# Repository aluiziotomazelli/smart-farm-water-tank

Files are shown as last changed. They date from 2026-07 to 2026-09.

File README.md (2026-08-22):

# Smart Farm Water Tank Node






A modular, low-power IoT peripheral node based on the **Seeed Studio XIAO ESP32-C3**, designed to accurately monitor water reservoir levels (via ultrasonic distance sensing and geometric tank modeling), detect high-water overflow/backup state (via float switch with deep-sleep GPIO wakeup), monitor battery health, provide visual diagnostics via a status LED, and transmit telemetry via **ESP-NOW** to the central Smart Farm Hub.

---

## 1. Physical Principle & Measurement Model

- **Ultrasonic Level Sensing:** Measures distance from sensor face to water surface using ultrasonic echo timing. Supports multi-sampling (default 11 samples), noise variance rejection, and automatic retries on weak signal or high variance.
- **Non-Linear Geometric Tank Modeling (`TankGeometry`):** Lookup-table (LUT) and piecewise model for stacked cylindrical tank geometry that converts raw distance (cm) into accurate volume (L) and permille ($\text{‰}$) capacity.
- **Auxiliary Float Switch (`FloatSwitch`):** Redundant physical switch detecting full reservoir conditions. Features multi-sample hysteresis filtering (`FILL_STATE_CONFIRMATIONS_REQUIRED = 2`) to eliminate water ripple turbulence noise, and arms GPIO deep sleep wakeup when tank is empty/falling.
- **Battery Health Monitoring (`BatteryMonitor`):** Measures 1S LiFePO4 / Li-Po battery voltage via calibrated ADC divider, tracking percentage and operating state (`NORMAL`, `LOW`, `CRITICAL`).
- **Power Rail Control (`PowerControl`):** Dedicated power gate rail energizing the ultrasonic sensor only during measurement intervals (~50ms warmup + sample duration) to achieve minimal quiescent sleep current.

---

## 2. Hardware Pinout & Schematic (Seeed XIAO ESP32-C3)

### Pinout Table

| Pin | GPIO | Constant | Description |
| :--- | :--- | :--- | :--- |
| **D0**  | `GPIO 2`  | `FLOAT_SWITCH_GPIO`  | Float switch input with deep-sleep GPIO wakeup trigger |
| **D1**  | `GPIO 3`  | `BATTERY_LEVEL_GPIO` | ADC battery divider input (ADC1_CH3) |
| **D2**  | `GPIO 4`  | `US_TRIG_GPIO` | Ultrasonic sensor Trigger pulse output |
| **D3**  | `GPIO 5`  | `US_ECHO_GPIO` | Ultrasonic sensor Echo input pulse |
| **D4**  | `GPIO 6`  | *(Free)* | General purpose I/O |
| **D5**  | `GPIO 7`  | *(Free)* | General purpose I/O |
| **D6**  | `GPIO 21` | *(Free)* | UART0 TX (Debug serial console) |
| **D7**  | `GPIO 20` | *(Free)* | UART0 RX (Debug serial console) |
| **D8**  | `GPIO 8`  | `STATUS_LED_GPIO` | Status LED visual indicator (diagnostic / state feedback) |
| **D9**  | `GPIO 9`  | `BOOT_BUTTON_GPIO` | Hardware BOOT button / manual OTA mode trigger |
| **D10** | `GPIO 10` | `POWER_GPIO` | Ultrasonic sensor VCC power gating rail |

---

## 3. Architecture & Operational Lifecycle

```
                      +-----------------------------+
                      |         ESP32-C3 Boot       |
                      +-----------------------------+
                                     │
                                     ▼
                      +-----------------------------+
                      |     WaterTankApp::init()    | (LED task, NVS, WiFi, ESP-NOW)
                      +-----------------------------+
                                     │
                                     ▼
                      +-----------------------------+
                      |    Sensor Power Rail ON     | (PowerControl GPIO 10)
                      +-----------------------------+
                                     │
                                     ▼
                      +-----------------------------+
                      |  Read Aux Sensors (Bat/FS)  | (During ~50ms sensor warmup)
                      +-----------------------------+
                                     │
                                     ▼
                      +-----------------------------+
                      | Ultrasonic Sample & Logic   | (Level permille & fill state)
                      +-----------------------------+
                                     │
                                     ▼
                      +-----------------------------+
                      |   Power OFF Sensor Rail     |
                      +-----------------------------+
                                     │
                                     ▼
                      +-----------------------------+
                      | Send Telemetry via ESP-NOW  | (WaterLevelReport + LED TX Pulse)
                      +-----------------------------+
                                     │
                                     ▼
                      +-----------------------------+
                      | Listen Window (200 ms)      | (Process commands: Sync, OTA, Reboot)
                      +-----------------------------+
                                     │
                                     ▼
                      +-----------------------------+
                      | Save State & Stop LED Task  | (AppStorage NVS commit)
                      +-----------------------------+
                                     │
                                     ▼
                      +-----------------------------+
                      |      Enter Deep Sleep       | (Timer + FloatSwitch GPIO Wakeup)
                      +-----------------------------+
```

### Status LED Visual Indicator (`ILedController`)

A background FreeRTOS task animates the status LED non-blockingly without delaying telemetry or sleep routines:

| Pattern | Description |
| :--- | :--- |
| `BOOT_SUCCESS` | 2 short pulses (100ms on / 100ms off) confirming healthy boot initialization |
| `ERROR_BURST` | 5 rapid pulses (50ms on / 50ms off) on hardware or communication faults |
| `PAIRING_MODE` | Continuous 200ms blinking while searching / registering with the Hub |
| `TX_PULSE` | Quick 30ms single blip when broadcasting a telemetry report |
| `OTA_UPDATING` | Continuous 100ms blinking during firmware download and flash write |

---

## 4. Telemetry Format (`WaterLevelReport`)

ESP-NOW telemetry payload packed with fixed binary representation:

```cpp
struct WaterLevelReport
{
    uint16_t level_permille;        ///< Water level in permille (0 - 1000 ‰)
    uint32_t volume_liters;         ///< Calculated water volume in liters
    int16_t  distance_cm;           ///< Raw measured distance from sensor to surface (0.1 cm resolution)
    uint16_t battery_mv;            ///< Node battery voltage in millivolts
    uint8_t  battery_percent;       ///< Node battery percentage (0 - 100%)
    farm::BatteryState battery_state;///< Node battery health state (UNKNOWN, CRITICAL, LOW, NORMAL, FULL)
    farm::FillState fill_state;     ///< Tank fill trend (EMPTY, FILLING, DRAINING, FULL, STABLE)
    farm::SensorStatus status;      ///< Sensor hardware status (OK, ERROR_OUT_OF_RANGE, HW_FAULT)
    bool     float_switch_is_full;  ///< Physical float switch state (true = full)
    bool     backup_mode_active;    ///< True if ultrasonic failed and relying on float switch
    uint64_t unix_time;             ///< UTC Epoch timestamp in milliseconds (0 if unsynced)
};
```

---

## 5. Building and Flashing Firmware

### Prerequisites
- ESP-IDF **v5.1+** (v5.5 recommended)

```bash
# Export ESP-IDF environment
source $HOME/dev/esp/esp-idf/export.sh

# Build target firmware
idf.py set-target esp32c3
idf.py build

# Flash and monitor connected device
idf.py -p /dev/ttyACM0 flash monitor
```

---

## 6. Running Host-Based Tests (Linux)

The codebase is fully decoupled with abstract interfaces and GoogleTest / GoogleMock fixtures, allowing 100% of domain logic, geometry calculations, storage envelopes, and application orchestrator workflows to run natively on Linux.

### Running Individual Test Suites

```bash
# Test geometry lookup and volume calculations
cd host_test/test_water_tank_geometry
idf.py build && ./build/test_water_tank_geometry.elf

# Test edge logic, fill state filtering, and sleep duration calculations
cd host_test/test_water_tank_logic
idf.py build && ./build/test_water_tank_logic.elf

# Test complete application lifecycle, ESP-NOW, OTA, LED, and persistence
cd host_test/test_water_tank_app
idf.py build && ./build/test_water_tank_app.elf
```

### Running All Test Suites with CTest

```bash
cd host_test
mkdir -p build && cd build
cmake ..
ctest --output-on-failure
```

### Generating Unified Code Coverage

```bash
cd host_test/build
cmake --build . --target run_all_tests
# HTML coverage report generated in host_test/coverage/index.html
```

---

## 7. System & Configuration Notes

### Main Task Stack Size
Due to concurrent initialization of `WiFiManager`, `EspNowManager`, UDP Logger, NVS storage backends, and sensors, the peak stack consumption during startup reaches ~3.8 KB.
The main task stack size must be set to at least **8 KB (8192 bytes)**:
```ini
CONFIG_ESP_MAIN_TASK_STACK_SIZE=8192
```
Stack high water mark is monitored at startup and before entering deep sleep via `IHalFreertos::task_get_stack_high_water_mark()` (returns remaining space in bytes).

---

## 8. License

This project is licensed under the MIT License - see the [LICENSE](LICENSE) file for details.

### Third-Party Acknowledgments

- **[ESP-IDF](https://github.com/espressif/esp-idf)**: Copyright (c) Espressif Systems (Shanghai) CO LTD — Licensed under the [Apache License 2.0](https://www.apache.org/licenses/LICENSE-2.0).
- **[Embedded Template Library (ETL)](https://www.etlcpp.com/)**: Copyright (c) John Wellbelove — Licensed under the [MIT License](https://opensource.org/licenses/MIT).
- **[GoogleTest / GoogleMock](https://github.com/google/googletest)**: Copyright (c) Google LLC — Licensed under the [BSD-3-Clause License](https://opensource.org/licenses/BSD-3-Clause).

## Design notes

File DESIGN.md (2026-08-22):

# Smart Farm - Water Tank Node Architecture

## 1. Overview

The **Water Tank Node** is a battery-powered, deep-sleep edge node within the Smart Farm ecosystem. Its primary function is to accurately measure water levels, monitor battery health, execute edge application logic, and transmit telemetry reports to the central Gateway/Hub via ESP-NOW.

---

## 2. System Architecture & Lifecycle

The node implements a deterministic **run-to-completion** operational model designed to minimize active MCU runtime:

```
[Reset / Wakeup] ──► [Init (LED, Storage, WiFi, ESP-NOW, Sensors)]
                           │
                           ▼
                    [Sensor Rail ON] ──► [Aux Read (Battery, FloatSwitch)]
                           │
                           ▼
                    [Ultrasonic Multi-Sample] ──► [Sensor Rail OFF]
                           │
                           ▼
                    [Edge Logic & Fill State Confirmation]
                           │
                           ▼
                    [ESP-NOW WaterLevelReport Transmission (LED TX Pulse)]
                           │
                           ▼
                    [Listen Window (200 ms for Hub Commands)]
                           │
                           ▼
                    [Save State & Stop LED Controller]
                           │
                           ▼
                    [Enter Deep Sleep (Timer + FloatSwitch Wakeup)]
```

### 2.1 Dependency Injection & HAL Decoupling
All hardware-specific APIs (GPIO, ADC, Sleep, Timers, FreeRTOS, NVS, Wi-Fi, System) are abstracted through pure virtual interfaces (`idf_hals` and `smart-farm-common`). The core application orchestrator (`WaterTankApp`) and domain logic (`WaterTankLogic`, `TankGeometry`) have zero direct dependencies on ESP-IDF hardware drivers, enabling comprehensive unit testing on host Linux.

---

## 3. Time Synchronization & Clock Architecture

### 3.1 Design Principles

- **Offline / ESP-NOW Synchronization**: The node does not maintain a continuous Wi-Fi/internet connection for SNTP polling. Time synchronization is received wirelessly from the Hub via ESP-NOW protocol messages.
- **Hardware RTC Persistence**: The ESP32 system clock (`gettimeofday` / POSIX time) is maintained continuously across deep sleep cycles by the hardware RTC memory timer.
- **No Time Regression**: The system does NOT restore cached timestamps from NVS to the system clock on boot. This prevents clock skew and backward time jumps upon waking up.

---

### 3.2 Initialization & Setup

- **Dependency Injection**: The `TimeManager` (`components/time_manager`) is instantiated in `main.cpp` with its HAL dependencies (`HalSntp`, `HalSystemTime`) and injected by reference into `WaterTankApp`.
- **Encapsulated Setup**: During `WaterTankApp::init()`, the private helper `init_time_manager()` configures:
  - Timezone: POSIX string `<-04>4` (UTC-4, no DST).
  - SNTP: `use_dhcp_sntp = false` (local SNTP client disabled).

---

### 3.3 ESP-NOW Time Synchronization Workflow

```
[Hub] ──(ESP-NOW: SYNC_TIME)──> [WaterTankApp::listen_for_messages]
                                             │
                                             ▼
                             [WaterTankApp::process_command]
                                             │
                                             ▼
                        [WaterTankApp::sync_time_from_espnow]
                                             │
                       ┌─────────────────────┴─────────────────────┐
                       ▼                                           ▼
       [time_manager_.sync_from_time_packet]          [CoreStorage Update]
    (Sets System POSIX / ESP32 RTC Clock)        (has_valid_time = true,
                                                  last_sync_unix_time_ms)
```

1. **Message Reception**: During the execution window (`listen_for_messages()`), incoming messages are queued and evaluated by `process_command()`.
2. **Command Processing**: When a payload of `farm::CommandType::SYNC_TIME` (`0x43`) is received, the payload is cast to `farm::TimeSyncCommand`.
3. **Clock Update**: `sync_time_from_espnow()` converts the command to a `time_manager::TimeSyncPacket` (`sync_source = TimeSyncSource::ESP_NOW`) and passes it to `time_manager_.sync_from_time_packet(pkt)`.
4. **Audit State Commit**: On success, `CoreStorage` updates `has_valid_time = true` and `last_sync_unix_time_ms = timestamp_ms` for audit tracking, setting `pending_core_commit_ = true`.

---

### 3.4 Telemetry Sampling & Transmission

1. **Sensor Sample Timestamping**: In `WaterTankApp::run()`, immediately after reading the ultrasonic sensor, the node checks `time_manager_.is_synchronized()`:
   - If synchronized: `stats_.sample_timestamp_ms` = `time_manager_.get_timestamp_ms()`.
   - If unsynchronized: `stats_.sample_timestamp_ms` = `0`.
2. **Telemetry Report Transmission**: In `send_report()`, `farm::WaterLevelReport::unix_time` is populated with `stats_.sample_timestamp_ms` and sent to the Hub over ESP-NOW.

---

### 3.5 Data Structures & Field Definitions

| Data Structure | Field Name | Type | Description |
|---|---|---|---|
| `WaterTankStats` | `sample_timestamp_ms` | `uint64_t` | UTC epoch timestamp (ms) recorded at the exact moment of sensor reading in the current cycle. |
| `CoreStorage` | `has_valid_time` | `bool` | Persistence flag indicating whether the node has received at least one valid time synchronization. |
| `CoreStorage` | `last_sync_unix_time_ms` | `uint64_t` | Audit timestamp (ms) recording the epoch time when the last ESP-NOW sync occurred. |
| `farm::WaterLevelReport` | `unix_time` | `uint64_t` | Sample timestamp (ms) included in the telemetry payload sent to the Hub (`0` if unsynchronized). |

---

## 4. State Management & Storage

### 4.1 Storage Architecture
The node utilizes the `AppStorage<T, Magic, Version>` template pattern (`smart-farm-common`) with `StorageEnvelope`:
- **RTC Memory / RAM Caching**: Runtime state resides in memory and persists across deep sleep wakeups.
- **NVS Flash Throttling**: To maximize Flash endurance, commits to non-volatile storage are throttled to every `NVS_COMMIT_INTERVAL = 10` cycles (~50 minutes in normal operation) unless forced by critical events (e.g. firmware confirmation, time sync, reboot command).
- **Integrity Validation**: CRC32 checksums, magic words (`0x57544E56` for tank stats, `0x434F5245` for core), and schema versioning prevent corrupted reads.

---

## 5. Power & Deep Sleep Management

### 5.1 Power Gating
- The ultrasonic sensor is powered via a high-side P-MOSFET gate on `GPIO 10`. Power is asserted at the start of `run()` and deactivated immediately after valid sampling, reducing sensor standby draw from ~15 mA to 0 µA during sleep.

### 5.2 Dynamic Sleep Interval Calculation
`WaterTankLogic::calculate_sleep_time_us()` determines deep sleep duration according to operational dynamics:
- **Filling / Draining Trend**: Accelerated sampling (~60s) to closely track rapid volume changes.
- **Stable Reservoir**: Extended sampling (300s / 5 min) for battery conservation.
- **Critical Battery / Error State**: Fallback backoff interval to prevent brownout loops.

### 5.3 Float Switch GPIO Wakeup
When the reservoir is empty or falling, `FloatSwitch::should_enable_wakeup()` enables the ESP32-C3 deep sleep GPIO wakeup on `GPIO 2`. A rising water level triggering the float switch immediately wakes the MCU without waiting for timer expiry.

---

## 6. Over-The-Air (OTA) Updates

### 6.1 Trigger Mechanisms
- **Hardware Trigger**: Long press of the BOOT button (`GPIO 9`) captured by `ButtonOtaTrigger`.
- **ESP-NOW Network Trigger**: Remote command (`farm::CommandType::START_OTA`) captured by `EspNowOtaTrigger`.

### 6.2 Execution & Rollback Protection
1. **Radio Handover**: ESP-NOW is stopped and Wi-Fi connects to the local AP using stored credentials.
2. **Download & Flash**: `OtaController` fetches the manifest and streams the firmware binary to the next OTA partition.
3. **Post-Boot Health Check**: Upon rebooting into the new image, `WaterTankApp::check_firmware_healthy()` verifies all peripheral inits. If healthy, the partition is confirmed (`esp_ota_mark_app_valid_cancel_rollback()`). If any init fails, the partition is rejected and the bootloader automatically rolls back to the previous stable firmware slot.

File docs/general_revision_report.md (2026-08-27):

# General Revision Report – Smart Farm Water-Tank Project

## 1. Code Base Overview
- **Modular, layered architecture** – core logic lives in `main/` while hardware-specific abstractions are isolated under `components/` (e.g., `ultrasonic_sensor`, `battery_monitor`, `float_switch`).
- **Dependency-Injection (DI) pattern** is used throughout (`WaterTankApp`, `WaterTankLogic`, `TankGeometry`, etc. receive interfaces via constructors or setters).
- **Interface-driven design** – every hardware domain (GPIO, ADC, NVS, Wi-Fi, ESP-NOW) is wrapped in pure-virtual “hal” interfaces (`i_hal_gpio.hpp`, `i_hal_adc_calibration.hpp`, …) that enable pure-host unit testing.
- **Pure C++ abstractions** – no direct ESP-IDF primitives are exposed above the HAL layer, making the domain code portable to Linux test runners.

## 2. SOLID Alignment
| SOLID Principle | Observed Practices | Comments / Recommendations |
|---|---|---|
| **Single Responsibility** | Each component (`UltrasonicController`, `WaterTankLogic`, `BatteryMonitor`, `FloatSwitchController`) has a clearly defined responsibility (sample, interpret, power-gate, report, etc.). | ✅ Well-aligned. |
| **Open/Closed** | Extensibility is achieved via abstract interfaces (`i_ultrasonic_processor.hpp`, `i_water_tank_nvs.hpp`). New sensor types or storage back-ends can be added without modifying existing code. | ✅ Good. Keep versioning of interfaces to avoid breakage. |
| **Liskov Substitution** | All concrete HAL classes implement the same virtual API and are used only through those abstractions, guaranteeing substitutability. | ✅ Strong adherence. |
| **Interface Segregation** | Very small, purpose-specific interfaces (`i_hal_gpio.hpp`, `i_hal_system_time.hpp`) are provided instead of monolithic "catch-all" bases. | ✅ Clean. |
| **Dependency Inversion** | High-level application (`WaterTankApp`) depends on abstractions (`ILevelSensor`, `IWaterTankStorage`, `ITimeManager`) rather than concrete ESP-IDF drivers. | ✅ Effective; ensure future refinements keep the same abstraction boundaries. |

**Overall SOLID Strength:** Very good – the codebase is organized around abstractions, enabling testability and reuse. Minor refactoring opportunities exist around versioning of storage schemas to keep the system forward-compatible.

## 3. Testing Strategy
- **Host-based test suite** (`host_test/`) runs 100’ % of domain logic on Linux using GoogleTest/GoogleMock.
- **Three logical test suites**: geometry/volume calculations, edge-logic & sleep-time algorithms, full-stack application (ESP-NOW, OTA, LED).
- **Unified coverage generation** – `run_all_tests` target builds all suites and produces an HTML coverage report.
- **CI pipelines** (GitHub Actions) automatically build, test, and publish coverage badges.

**Strengths**
- Comprehensive coverage (>90’ % expected) of non-hardware code.
- Test isolation enables regression testing without flashing hardware.

**Opportunities**
- Add **property-based tests** for mathematical helpers (`TankGeometry`) to catch edge-case conversions.
- Experiment with **mock-based integration tests** for ESP-NOW command flow to increase unit-test depth before hardware integration.
- Document test-suite entry points in the top-level `README` for contributors.

## 4. Documentation Quality
- **README.md** – provides high-level intro, build instructions, hardware pinout, architecture diagram, and flashing steps.
- **DESIGN.md** – deep dive into run-to-completion lifecycle, time-sync design, telemetry schema, power management, and OTA flow.
- **Component-level API docs** (`API.md` in each component) expose public structs, enums, and functions with clear parameter descriptions.
- **Changelog** and **LICENSE** are maintained.

**Strengths**
- Well-structured markdown hierarchy, easy to read.
- Clear diagrams (run-to-completion flowchart, pinout table).
- Telemetry protocol struct is fully documented.

**Opportunities**
- Generate **automatic API docs** (e.g., Doxygen or clang-doc) and publish them as static site for browsing.
- Add "How-to-contribute" section describing branching, PR workflow, and CI expectations.
- Include **run-time stack-size and high-water-mark** expectations in docs (currently only in `DESIGN.md`).

## 5. General Revision Recommendations
| Area | Recommendation | Rationale |
|---|---|---|
| **Code Consistency** | Adopt a **pre-commit formatting check** (clang-format) and enforce via CI. | Keeps style uniform, reduces noise in reviews. |
| **Static Analysis** | Enable **Clang-Tidy** with ESP-IDF rules in the build pipeline. | Early detection of potential undefined-behaviour, resource leaks, and violation of ESP-IDF best-practices. |
| **Versioned Interfaces** | Consider adding a **semantic version tag** (e.g., `IVersioned<T>`) to major abstractions to guard against ABI breakage when evolving storage formats. | Improves forward compatibility across firmware releases. |
| **Telemetry Schema Evolution** | Publish a **schema version field** inside `WaterLevelReport` and document migration paths. | Allows graceful addition of new fields without breaking downstream consumers. |
| **Testing Documentation** | Add a "Running Tests Locally" subsection to `README.md` with concrete commands (`cmake`, `ctest`, coverage). | Lowers onboarding friction for new contributors. |
| **Performance Optimizations** | Profile **deep-sleep wake-up latency** and **stack high-water-mark** on a few representative hardware configurations. Document results. | Guarantees that stack size (`CONFIG_ESP_MAIN_TASK_STACK_SIZE=8192`) remains sufficient after future feature additions. |
| **Security** | Review **ESP-NOW** payload sanitization and consider adding a **message authentication tag** (e.g., HMAC) to prevent spoofing. | Improves robustness of remote command channel. |
| **Accessibility** | Add brief **explanations for non-technical stakeholders** in `DESIGN.md` (e.g., why ultrasonic sensor power-gating matters for battery life). | Enhances knowledge transfer within the broader Smart Farm team. |

## 6. Summary
- The project exhibits a clean, SOLID-compliant architecture with strong DI and interface-driven design.
- Test coverage is thorough for non-hardware domains, supported by automated CI and coverage reporting.
- Documentation is extensive and well organized, though could benefit from automated API generation, additional contribution guidance, and minor schema-versioning documentation.
- The outlined recommendations aim to reinforce code quality, future-proof the telemetry protocol, and streamline contributor onboarding without altering any existing source files.

*Prepared as a high-level revision overview. No code modifications have been performed.*

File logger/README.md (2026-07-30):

# UDP Remote Logger Receiver

Este diretório contém o script utilitário para receber e gravar os logs transmitidos por rede (UDP) a partir dos dispositivos da fazenda inteligente (como o Water Tank e o Hub).

## Como funciona
Os dispositivos, ao estarem conectados na rede Wi-Fi, redirecionam a saída padrão do `ESP_LOGx` para pacotes UDP na porta `4444`. 
Este script escuta essa porta, adiciona um timestamp com milissegundos e o IP do dispositivo de origem, imprimindo na tela e salvando as saídas em arquivo de texto.

## Requisitos
- Apenas Python 3 instalado (usa módulos da biblioteca padrão do Python).

## Como Executar

1. Abra o terminal na pasta deste logger:
   ```bash
   cd logger
   ```

2. Execute o script receiver:
   ```bash
   python3 udp_logger.py
   ```

Os logs serão exibidos no console em tempo real e armazenados em `field_test_logs.txt`.

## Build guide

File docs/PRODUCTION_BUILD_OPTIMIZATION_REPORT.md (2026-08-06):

# Production Build Optimization Report via `sdkconfig` (ESP-IDF / ESP32-C3)

---

## Quick Start: How to Build for Production & Development

### 1. Build for Development / Testing (Default Profile)
Running standard `idf.py build` automatically uses `sdkconfig.defaults.dev` (with `INFO` logs, `-Og` debug optimization, and console output enabled):
```bash
source $HOME/dev/esp/esp-idf/export.sh
idf.py build
```

### 2. Build for Production (Field Release)
To build an optimized production binary (silenced `WARN` logs, `-Os` size optimization, silent assertions, no console output):
```bash
source $HOME/dev/esp/esp-idf/export.sh
idf.py -DSDKCONFIG_DEFAULTS="sdkconfig.defaults;sdkconfig.defaults.esp32c3;sdkconfig.defaults.prod" reconfigure build
```
Tip: You may need to clean your build directory, sdconfig and dependencies.lock 
```bash
rm -rf build sdkconfig dependencies.lock
```

---

## 1. Executive Summary

The **Smart Farm Water Tank** firmware operates on battery power using a *run-to-completion* design pattern paired with *Deep Sleep*.

In a **Production** environment:
- **Shorter CPU active time = Extended battery lifespan.**
- **Smaller binary image = Faster and safer OTA firmware updates.**
- **Log level reduction = Elimination of UART/USB I/O blocking and reduced Flash footprint.**

This document details optimization recommendations and their performance impact when configuring the build system (`sdkconfig.defaults`) for production releases.

---

## 2. Logging and Console (I/O) Optimizations

### A. Application Default Log Level (`CONFIG_LOG_DEFAULT_LEVEL`)
- **Current State**: `CONFIG_LOG_DEFAULT_LEVEL_INFO=y` (`Level 3 - INFO`).
- **Production Recommendation**: `CONFIG_LOG_DEFAULT_LEVEL_WARN=y` (`Level 2 - WARN`) or `CONFIG_LOG_DEFAULT_LEVEL_ERROR=y` (`Level 1 - ERROR`).
- **Impact**:
  1. **Binary Footprint Reduction**: Removes hundreds of `ESP_LOGI` format string constants from Flash memory.
  2. **Execution Speed**: Eliminates CPU cycles spent formatting strings and transmitting via UART/USB during every wake cycle (~5 ms to ~15 ms saved per cycle).

### B. Bootloader Log Level (`CONFIG_BOOTLOADER_LOG_LEVEL`)
- **Current State**: `CONFIG_BOOTLOADER_LOG_LEVEL_INFO=y` (`Level 3`).
- **Production Recommendation**: `CONFIG_BOOTLOADER_LOG_LEVEL_WARN=y` or `CONFIG_BOOTLOADER_LOG_LEVEL_NONE=y`.
- **Impact**: Reduces Bootloader execution time by approximately **10 ms to 20 ms** on every CPU reset (deep sleep wakeup).

### C. Console Output (`CONFIG_ESP_CONSOLE_DEV_NUM` / `CONFIG_ESP_CONSOLE_NONE`)
- **Current State**: `CONFIG_ESP_CONSOLE_USB_SERIAL_JTAG=y`.
- **Production Recommendation**: If field devices do not require physical USB-Serial console debugging, set `CONFIG_ESP_CONSOLE_NONE=y` or disable log colors (`CONFIG_LOG_COLORS=n`).
- **Impact**: Prevents CPU execution stalls when attempting to transmit over USB-Serial JTAG when no host PC is connected.

---

## 3. Compiler and Binary Size Optimizations

### A. GCC Optimization Level (`CONFIG_COMPILER_OPTIMIZATION`)
- **Current State**: `CONFIG_COMPILER_OPTIMIZATION_DEBUG=y` (`-Og`).
- **Production Recommendation**: `CONFIG_COMPILER_OPTIMIZATION_SIZE=y` (`-Os`).
- **Impact**:
  - Enables aggressive GCC code size optimizations.
  - Reduces the `.bin` firmware image size by **20% to 35%**.
  - Improves ESP32-C3 I-Cache efficiency and reduces OTA download transfer time over Wi-Fi.

### B. Assertion Handling (`CONFIG_COMPILER_OPTIMIZATION_ASSERTIONS`)
- **Current State**: `CONFIG_COMPILER_OPTIMIZATION_ASSERTIONS_ENABLE=y`.
- **Production Recommendation**: `CONFIG_COMPILER_OPTIMIZATION_ASSERTIONS_SILENT=y`.
- **Impact**: Preserves system safety (resets the CPU on assertion failure) while **stripping text filenames and line numbers**, saving Flash memory without compromising runtime safety.

---

## 4. PHY Radio and Power Optimizations

### A. Wi-Fi / ESP-NOW Maximum TX Power (`CONFIG_ESP_PHY_MAX_TX_POWER`)
- **Production Recommendation**: Consider lowering maximum PHY radio transmit power from default 20 dBm to ~15–17 dBm (e.g. `CONFIG_ESP_PHY_MAX_TX_POWER=72`).
- **Impact**:
  - Peak radio transmission current drops from **~340 mA to ~190 mA**.
  - Significantly extends battery health and capacity for nodes located within close/medium range of the Hub.

### B. Serial Flash Access Mode (`CONFIG_ESPTOOLPY_FLASHMODE`)
- **Production Recommendation**: If the target hardware board supports 4 data lines (Quad SPI), configure `CONFIG_ESPTOOLPY_FLASHMODE_QIO=y` at 80 MHz instead of Dual I/O (`DIO`).
- **Impact**: Doubles Flash fetch throughput during code execution, reducing total active uptime prior to entering Deep Sleep.

---

## 5. Security and OTA Production Settings

### A. Disable Insecure HTTP Support
- **Current State**: `CONFIG_ESP_HTTPS_OTA_ALLOW_HTTP=y`.
- **Production Recommendation**: Set `CONFIG_ESP_HTTPS_OTA_ALLOW_HTTP=n` (enforce HTTPS once migrating to production cloud/server infrastructure).

---

## 6. Recommended `sdkconfig.defaults.production` Profile

```ini
# =============================================================================
# Production Build Defaults - Smart Farm Water Tank
# =============================================================================

# 1. Compiler Optimization for Size (-Os)
CONFIG_COMPILER_OPTIMIZATION_SIZE=y
# CONFIG_COMPILER_OPTIMIZATION_DEBUG is not set
CONFIG_COMPILER_OPTIMIZATION_ASSERTIONS_SILENT=y

# 2. Logging Optimization (WARN Level & Silence Bootloader)
CONFIG_LOG_DEFAULT_LEVEL_WARN=y
# CONFIG_LOG_DEFAULT_LEVEL_INFO is not set
CONFIG_LOG_DEFAULT_LEVEL=2
CONFIG_BOOTLOADER_LOG_LEVEL_WARN=y
# CONFIG_BOOTLOADER_LOG_LEVEL_INFO is not set
CONFIG_BOOTLOADER_LOG_LEVEL=2
CONFIG_LOG_COLORS=n

# 3. System Task & Rollback Settings
CONFIG_BOOTLOADER_APP_ROLLBACK_ENABLE=y
CONFIG_PARTITION_TABLE_CUSTOM=y
CONFIG_ESP_MAIN_TASK_STACK_SIZE=8192

# 4. Target & Flash
CONFIG_IDF_TARGET="esp32c3"
CONFIG_FREERTOS_UNICORE=y
CONFIG_PM_ENABLE=y
```

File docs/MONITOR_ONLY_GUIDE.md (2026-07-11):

# Guide: Monitor-Only Mode (Without Physical Float Switch)

If you are deploying the system for monitoring only and cannot connect a physical float switch, follow these steps to ensure the battery is protected and the logic remains consistent.

## 1. Prevent Battery Drain in Backup Mode

In the event of an ultrasonic sensor failure, the system enters **Backup Mode**. Without a physical float switch, the system might default to a state of "Tank Not Full," causing it to wake up every 15 seconds to retry the sensor, which will quickly drain the battery.

To prevent this, configure the `FloatSwitch` in `water_tank_app.cpp` so that an open (disconnected) pin is interpreted as **"Tank Full"** (triggering the longer 5-minute sleep).

### Recommended Configuration

Update the `float_switch_config` in `smart-farm-water-tank/main/main.cpp`:

```cpp
floatswitch::Config float_switch_config = {
    .gpio = FLOAT_SWITCH_GPIO,
    .normally_open = true, // Open contact = Tank Full
    .debounce_time_us = 50000,
    .active_level = floatswitch::ActiveLevel::LOW, // internal pull-up will be enabled naturally yielding an open contact
    .wakeup_on = floatswitch::WakeupCondition::NEVER}; // Disable pin wakeup to prevent noise from waking the device
```

## 2. Summary of Configuration Values

| Parameter | Recommended Value | Reason |
| :--- | :--- | :--- |
| `normally_open` | `true` | Ensures that an open/disconnected circuit is interpreted as "Full". |
| `active_level` | `LOW` | Automatically enables the internal pull-up resistor. When the pin is disconnected, it stays HIGH, resulting in an "open" reading. |
| `wakeup_on` | `NEVER` | Prevents the disconnected pin from causing accidental wakeups from electrical noise. |

## 3. Telemetry Impact

With this configuration:
- The `float_switch_is_full` field in the ESP-NOW report will always be `true`.
- If the ultrasonic sensor fails, the system will sleep for `TIMER_STABLE_US` (5 minutes) instead of the 15-second retry timer, preserving your battery until you can fix the sensor.

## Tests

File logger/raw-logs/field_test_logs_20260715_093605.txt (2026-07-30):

[2026-07-15 09:36:07.473] [192.168.1.64] I (124563) UsSensor: 35.4-0, 35.6-0, 35.5-0, 35.5-0, 35.5-0, 35.5-0, 35.6-0
[2026-07-15 09:36:07.510] [192.168.1.64] I (124583) WaterTankApp: Distance: 35.5 - UsResult 0 | Battery: 3810
[2026-07-15 09:36:13.593] [192.168.1.64] I (130683) UsSensor: 35.4-0, 35.6-0, 35.5-0, 36.5-0, 36.5-0, 36.5-0, 36.5-0
[2026-07-15 09:36:13.622] [192.168.1.64] I (130703) WaterTankApp: Distance: 36.1 - UsResult 0 | Battery: 3810
[2026-07-15 09:36:19.713] [192.168.1.64] I (136803) UsSensor: 36.1-0, 36.2-0, 36.2-0, 36.5-0, 36.5-0, 36.5-0, 36.5-0
[2026-07-15 09:36:19.741] [192.168.1.64] I (136823) WaterTankApp: Distance: 36.4 - UsResult 0 | Battery: 3810
[2026-07-15 09:36:25.840] [192.168.1.64] I (142923) UsSensor: 36.1-0, 36.2-0, 36.2-0, 36.2-0, 36.2-0, 36.2-0, 36.5-0
[2026-07-15 09:36:25.891] [192.168.1.64] I (142973) WaterTankApp: Distance: 36.2 - UsResult 0 | Battery: 3810
[2026-07-15 09:36:31.993] [192.168.1.64] I (149073) UsSensor: 36.4-0, 36.5-0, 36.5-0, 36.5-0, 36.2-0, 36.2-0, 36.2-0
[2026-07-15 09:36:32.012] [192.168.1.64] I (149093) WaterTankApp: Distance: 36.4 - UsResult 0 | Battery: 3810
[2026-07-15 09:36:38.102] [192.168.1.64] I (155193) UsSensor: 36.1-0, 36.2-0, 36.2-0, 36.2-0, 36.2-0, 36.2-0, 36.5-0
[2026-07-15 09:36:38.131] [192.168.1.64] I (155213) WaterTankApp: Distance: 36.2 - UsResult 0 | Battery: 3810
[2026-07-15 09:36:44.222] [192.168.1.64] I (161313) UsSensor: 36.1-0, 36.2-0, 36.2-0, 36.2-0, 36.2-0, 36.2-0, 36.2-0
[2026-07-15 09:36:44.250] [192.168.1.64] I (161333) WaterTankApp: Distance: 36.2 - UsResult 0 | Battery: 3810
[2026-07-15 09:36:50.344] [192.168.1.64] I (167433) UsSensor: 37.0-0, 37.1-0, 36.2-0, 36.2-0, 36.2-0, 36.2-0, 37.2-0
[2026-07-15 09:36:50.371] [192.168.1.64] I (167453) WaterTankApp: Distance: 36.6 - UsResult 0 | Battery: 3810
[2026-07-15 09:36:56.462] [192.168.1.64] I (173553) UsSensor: 35.7-0, 35.9-0, 35.9-0, 35.9-0, 35.8-0, 35.9-0, 37.1-0
[2026-07-15 09:36:56.490] [192.168.1.64] I (173573) WaterTankApp: Distance: 36.0 - UsResult 0 | Battery: 3810
[2026-07-15 09:37:02.582] [192.168.1.64] I (179673) UsSensor: 35.8-0, 35.9-0, 35.9-0, 35.9-0, 35.9-0, 35.9-0, 35.9-0
[2026-07-15 09:37:02.610] [192.168.1.64] I (179693) WaterTankApp: Distance: 35.8 - UsResult 0 | Battery: 3810
[2026-07-15 09:37:08.702] [192.168.1.64] I (185793) UsSensor: 35.8-0, 35.8-0, 35.8-0, 35.9-0, 35.9-0, 35.8-0, 35.9-0
[2026-07-15 09:37:08.730] [192.168.1.64] I (185813) WaterTankApp: Distance: 35.8 - UsResult 0 | Battery: 3810
[2026-07-15 09:37:14.821] [192.168.1.64] I (191913) UsSensor: 35.8-0, 35.9-0, 35.9-0, 35.9-0, 35.9-0, 35.9-0, 36.8-0
[2026-07-15 09:37:14.850] [192.168.1.64] I (191933) WaterTankApp: Distance: 36.0 - UsResult 0 | Battery: 3810
[2026-07-15 09:37:20.941] [192.168.1.64] I (198033) UsSensor: 36.7-0, 36.8-0, 36.8-0, 36.8-0, 36.9-0, 36.8-0, 36.9-0
[2026-07-15 09:37:20.971] [192.168.1.64] I (198053) WaterTankApp: Distance: 36.8 - UsResult 0 | Battery: 3810
[2026-07-15 09:37:27.076] [192.168.1.64] I (204153) UsSensor: 36.7-0, 36.9-0, 36.9-0, 36.8-0, 36.8-0, 36.9-0, 35.9-0
[2026-07-15 09:37:27.096] [192.168.1.64] I (204173) WaterTankApp: Distance: 36.7 - UsResult 0 | Battery: 3804
[2026-07-15 09:37:33.181] [192.168.1.64] I (210273) UsSensor: 36.4-0, 36.5-0, 36.5-0, 36.5-0, 36.4-0, 36.5-0, 36.5-0
[2026-07-15 09:37:33.216] [192.168.1.64] I (210293) WaterTankApp: Distance: 36.5 - UsResult 0 | Battery: 3810
[2026-07-15 09:37:39.302] [192.168.1.64] I (216393) UsSensor: 36.4-0, 36.5-0, 36.5-0, 36.4-0, 36.5-0, 36.5-0, 36.5-0
[2026-07-15 09:37:39.329] [192.168.1.64] I (216413) WaterTankApp: Distance: 36.5 - UsResult 0 | Battery: 3810
[2026-07-15 09:37:45.421] [192.168.1.64] I (222513) UsSensor: 36.4-0, 36.5-0, 36.5-0, 36.5-0, 36.5-0, 36.5-0, 36.5-0
[2026-07-15 09:37:45.449] [192.168.1.64] I (222533) WaterTankApp: Distance: 36.5 - UsResult 0 | Battery: 3810
[2026-07-15 09:37:51.546] [192.168.1.64] I (228633) UsSensor: 36.4-0, 36.5-0, 36.5-0, 36.5-0, 36.5-0, 36.5-0, 36.5-0
[2026-07-15 09:37:51.569] [192.168.1.64] I (228653) WaterTankApp: Distance: 36.5 - UsResult 0 | Battery: 3810
[2026-07-15 09:37:57.660] [192.168.1.64] I (234753) UsSensor: 36.4-0, 36.5-0, 36.5-0, 36.5-0, 36.5-0, 36.5-0, 36.5-0
[2026-07-15 09:37:57.690] [192.168.1.64] I (234773) WaterTankApp: Distance: 36.5 - UsResult 0 | Battery: 3810
[2026-07-15 09:38:03.780] [192.168.1.64] I (240873) UsSensor: 36.4-0, 36.4-0, 36.5-0, 36.5-0, 36.4-0, 36.5-0, 36.5-0
[2026-07-15 09:38:03.809] [192.168.1.64] I (240893) WaterTankApp: Distance: 36.5 - UsResult 0 | Battery: 3810
[2026-07-15 09:38:09.900] [192.168.1.64] I (246993) UsSensor: 37.4-0, 37.5-0, 37.5-0, 37.5-0, 37.5-0, 36.5-0, 36.5-0
[2026-07-15 09:38:09.929] [192.168.1.64] I (247013) WaterTankApp: Distance: 37.2 - UsResult 0 | Battery: 3810
[2026-07-15 09:38:16.020] [192.168.1.64] I (253113) UsSensor: 36.4-0, 36.5-0, 36.5-0, 37.5-0, 37.5-0, 37.5-0, 37.5-0
[2026-07-15 09:38:16.056] [192.168.1.64] I (253133) WaterTankApp: Distance: 37.0 - UsResult 0 | Battery: 3810
[2026-07-15 09:38:22.140] [192.168.1.64] I (259233) UsSensor: 37.0-0, 37.5-0, 37.5-0, 37.5-0, 37.5-0, 37.1-0, 37.1-0
[2026-07-15 09:38:22.170] [192.168.1.64] I (259253) WaterTankApp: Distance: 37.3 - UsResult 0 | Battery: 3810
[2026-07-15 09:38:28.260] [192.168.1.64] I (265353) UsSensor: 37.4-0, 37.5-0, 37.2-0, 37.1-0, 37.1-0, 37.1-0, 37.1-0
[2026-07-15 09:38:28.291] [192.168.1.64] I (265373) WaterTankApp: Distance: 37.2 - UsResult 0 | Battery: 3810
[2026-07-15 09:38:34.380] [192.168.1.64] I (271473) UsSensor: 37.0-0, 37.1-0, 36.2-0, 37.1-0, 37.1-0, 37.5-0, 37.5-0
[2026-07-15 09:38:34.408] [192.168.1.64] I (271493) WaterTankApp: Distance: 37.1 - UsResult 0 | Battery: 3810
[2026-07-15 09:38:40.501] [192.168.1.64] I (277593) UsSensor: 36.8-0, 36.8-0, 37.2-0, 37.1-0, 37.1-0, 37.2-0, 37.1-0
[2026-07-15 09:38:40.529] [192.168.1.64] I (277613) WaterTankApp: Distance: 37.0 - UsResult 0 | Battery: 3810
[2026-07-15 09:38:46.620] [192.168.1.64] I (283713) UsSensor: 37.0-0, 37.1-0, 37.1-0, 36.8-0, 36.9-0, 36.8-0, 36.9-0
[2026-07-15 09:38:46.648] [192.168.1.64] I (283733) WaterTankApp: Distance: 37.0 - UsResult 0 | Battery: 3810
[2026-07-15 09:38:52.741] [192.168.1.64] I (289833) UsSensor: 36.7-0, 36.8-0, 36.8-0, 37.5-0, 36.8-0, 36.8-0, 36.8-0
[2026-07-15 09:38:52.768] [192.168.1.64] I (289853) WaterTankApp: Distance: 36.9 - UsResult 0 | Battery: 3810
[2026-07-15 09:38:58.860] [192.168.1.64] I (295953) UsSensor: 36.7-0, 36.8-0, 36.8-0, 36.8-0, 36.9-0, 36.8-0, 36.8-0
[2026-07-15 09:38:58.888] [192.168.1.64] I (295973) WaterTankApp: Distance: 36.8 - UsResult 0 | Battery: 3810
[2026-07-15 09:39:04.979] [192.168.1.64] I (302073) UsSensor: 36.7-0, 36.8-0, 36.8-0, 36.8-0, 36.9-0, 36.8-0, 36.8-0
[2026-07-15 09:39:05.010] [192.168.1.64] I (302093) WaterTankApp: Distance: 36.8 - UsResult 0 | Battery: 3810
[2026-07-15 09:39:11.099] [192.168.1.64] I (308193) UsSensor: 36.7-0, 36.8-0, 36.9-0, 36.8-0, 36.8-0, 36.8-0, 36.8-0
[2026-07-15 09:39:11.128] [192.168.1.64] I (308213) WaterTankApp: Distance: 36.8 - UsResult 0 | Battery: 3810
[2026-07-15 09:39:17.219] [192.168.1.64] I (314313) UsSensor: 33.3-0, 36.5-0, 36.5-0, 36.8-0, 36.8-0, 36.8-0, 36.8-0
[2026-07-15 09:39:17.278] [192.168.1.64] I (314363) WaterTankApp: Distance: 36.2 - UsResult 0 | Battery: 3806
[2026-07-15 09:39:23.370] [192.168.1.64] I (320463) UsSensor: 36.7-0, 36.8-0, 36.5-0, 36.5-0, 36.5-0, 36.5-0, 36.5-0
[2026-07-15 09:39:23.398] [192.168.1.64] I (320483) WaterTankApp: Distance: 36.6 - UsResult 0 | Battery: 3810
[2026-07-15 09:39:29.489] [192.168.1.64] I (326583) UsSensor: 36.7-0, 36.8-0, 36.8-0, 36.5-0, 36.5-0, 36.5-0, 36.8-0
[2026-07-15 09:39:29.517] [192.168.1.64] I (326603) WaterTankApp: Distance: 36.7 - UsResult 0 | Battery: 3810
[2026-07-15 09:39:35.609] [192.168.1.64] I (332703) UsSensor: 36.4-0, 36.5-0, 36.5-0, 36.5-0, 36.5-0, 36.5-0, 36.5-0
[2026-07-15 09:39:35.637] [192.168.1.64] I (332723) WaterTankApp: Distance: 36.5 - UsResult 0 | Battery: 3810
[2026-07-15 09:39:41.729] [192.168.1.64] I (338823) UsSensor: 36.4-0, 36.5-0, 36.5-0, 36.5-0, 36.5-0, 36.5-0, 36.5-0
[2026-07-15 09:39:41.757] [192.168.1.64] I (338843) WaterTankApp: Distance: 36.5 - UsResult 0 | Battery: 3810
[2026-07-15 09:39:47.850] [192.168.1.64] I (344943) UsSensor: 36.4-0, 36.5-0, 36.5-0, 36.5-0, 36.5-0, 36.5-0, 36.5-0
[2026-07-15 09:39:47.878] [192.168.1.64] I (344963) WaterTankApp: Distance: 36.5 - UsResult 0 | Battery: 3810
[2026-07-15 09:39:53.969] [192.168.1.64] I (351063) UsSensor: 37.4-0, 37.5-0, 37.5-0, 36.5-0, 36.5-0, 36.5-0, 36.5-0
[2026-07-15 09:39:53.997] [192.168.1.64] I (351083) WaterTankApp: Distance: 36.9 - UsResult 0 | Battery: 3810
[2026-07-15 09:40:00.093] [192.168.1.64] I (357183) UsSensor: 37.4-0, 37.5-0, 37.5-0, 37.5-0, 37.5-0, 37.5-0, 37.5-0
[2026-07-15 09:40:00.117] [192.168.1.64] I (357203) WaterTankApp: Distance: 37.5 - UsResult 0 | Battery: 3810
[2026-07-15 09:40:06.210] [192.168.1.64] I (363303) UsSensor: 37.4-0, 37.5-0, 37.5-0, 37.5-0, 37.5-0, 37.5-0, 37.5-0
[2026-07-15 09:40:06.240] [192.168.1.64] I (363323) WaterTankApp: Distance: 37.5 - UsResult 0 | Battery: 3810
[2026-07-15 09:40:12.330] [192.168.1.64] I (369423) UsSensor: 37.4-0, 37.5-0, 37.5-0, 37.5-0, 37.5-0, 37.5-0, 37.5-0
[2026-07-15 09:40:12.357] [192.168.1.64] I (369443) WaterTankApp: Distance: 37.5 - UsResult 0 | Battery: 3810
[2026-07-15 09:40:18.450] [192.168.1.64] I (375543) UsSensor: 37.1-0, 37.1-0, 37.1-0, 37.5-0, 37.5-0, 37.5-0, 37.1-0
[2026-07-15 09:40:18.479] [192.168.1.64] I (375563) WaterTankApp: Distance: 37.3 - UsResult 0 | Battery: 3810
[2026-07-15 09:40:24.570] [192.168.1.64] I (381663) UsSensor: 37.1-0, 37.1-0, 37.1-0, 37.1-0, 37.1-0, 37.1-0, 37.2-0
[2026-07-15 09:40:24.596] [192.168.1.64] I (381683) WaterTankApp: Distance: 37.1 - UsResult 0 | Battery: 3810
[2026-07-15 09:40:30.688] [192.168.1.64] I (387783) UsSensor: 37.0-0, 38.1-0, 38.1-0, 38.1-0, 38.1-0, 38.1-0, 37.1-0
[2026-07-15 09:40:30.717] [192.168.1.64] I (387803) WaterTankApp: Distance: 37.8 - UsResult 0 | Battery: 3810
[2026-07-15 09:40:36.808] [192.168.1.64] I (393903) UsSensor: 38.0-0, 38.1-0, 38.1-0, 38.1-0, 37.1-0, 37.1-0, 37.1-0
[2026-07-15 09:40:36.836] [192.168.1.64] I (393923) WaterTankApp: Distance: 37.7 - UsResult 0 | Battery: 3810
[2026-07-15 09:40:42.928] [192.168.1.64] I (400023) UsSensor: 38.0-0, 38.1-0, 38.1-0, 38.1-0, 36.8-0, 36.8-0, 37.8-0
[2026-07-15 09:40:42.962] [192.168.1.64] I (400043) WaterTankApp: Distance: 37.7 - UsResult 0 | Battery: 3810
[2026-07-15 09:40:49.051] [192.168.1.64] I (406143) UsSensor: 36.8-0, 36.8-0, 36.8-0, 36.8-0, 36.8-0, 37.8-0, 37.8-0
[2026-07-15 09:40:49.079] [192.168.1.64] I (406163) WaterTankApp: Distance: 37.1 - UsResult 0 | Battery: 3810
[2026-07-15 09:40:55.169] [192.168.1.64] I (412263) UsSensor: 37.7-0, 37.8-0, 37.8-0, 37.8-0, 36.9-0, 36.8-0, 36.8-0
[2026-07-15 09:40:55.196] [192.168.1.64] I (412283) WaterTankApp: Distance: 37.4 - UsResult 0 | Battery: 3810
[2026-07-15 09:41:01.292] [192.168.1.64] I (418383) UsSensor: 37.7-0, 37.8-0, 37.8-0, 36.8-0, 36.8-0, 36.8-0, 36.8-0
[2026-07-15 09:41:01.316] [192.168.1.64] I (418403) WaterTankApp: Distance: 37.2 - UsResult 0 | Battery: 3810
[2026-07-15 09:41:07.408] [192.168.1.64] I (424503) UsSensor: 36.7-0, 36.9-0, 36.8-0, 37.8-0, 37.8-0, 37.8-0, 37.7-0
[2026-07-15 09:41:07.436] [192.168.1.64] I (424523) WaterTankApp: Distance: 37.4 - UsResult 0 | Battery: 3810
[2026-07-15 09:41:13.528] [192.168.1.64] I (430623) UsSensor: 37.7-0, 37.5-0, 37.5-0, 37.8-0, 37.8-0, 37.8-0, 37.8-0
[2026-07-15 09:41:13.556] [192.168.1.64] I (430643) WaterTankApp: Distance: 37.7 - UsResult 0 | Battery: 3810
[2026-07-15 09:41:19.648] [192.168.1.64] I (436743) UsSensor: 37.7-0, 37.8-0, 37.8-0, 37.8-0, 37.4-0, 37.5-0, 37.5-0
[2026-07-15 09:41:19.676] [192.168.1.64] I (436763) WaterTankApp: Distance: 37.6 - UsResult 0 | Battery: 3810
[2026-07-15 09:41:25.767] [192.168.1.64] I (442863) UsSensor: 37.4-0, 37.5-0, 37.5-0, 37.5-0, 37.5-0, 37.5-0, 37.5-0
[2026-07-15 09:41:25.796] [192.168.1.64] I (442883) WaterTankApp: Distance: 37.5 - UsResult 0 | Battery: 3810
[2026-07-15 09:41:31.889] [192.168.1.64] I (448983) UsSensor: 37.4-0, 37.5-0, 37.5-0, 37.5-0, 37.5-0, 37.5-0, 37.5-0
[2026-07-15 09:41:31.916] [192.168.1.64] I (449003) WaterTankApp: Distance: 37.5 - UsResult 0 | Battery: 3810
[2026-07-15 09:41:38.008] [192.168.1.64] I (455103) UsSensor: 37.4-0, 37.5-0, 37.5-0, 37.5-0, 37.5-0, 37.5-0, 37.5-0
[2026-07-15 09:41:38.037] [192.168.1.64] I (455123) WaterTankApp: Distance: 37.5 - UsResult 0 | Battery: 3810
[2026-07-15 09:41:44.129] [192.168.1.64] I (461223) UsSensor: 37.4-0, 37.5-0, 37.5-0, 37.5-0, 37.5-0, 37.5-0, 37.5-0
[2026-07-15 09:41:44.157] [192.168.1.64] I (461243) WaterTankApp: Distance: 37.5 - UsResult 0 | Battery: 3810
[2026-07-15 09:41:50.247] [192.168.1.64] I (467343) UsSensor: 37.4-0, 37.4-0, 37.5-0, 37.5-0, 37.5-0, 37.5-0, 37.5-0
[2026-07-15 09:41:50.276] [192.168.1.64] I (467363) WaterTankApp: Distance: 37.5 - UsResult 0 | Battery: 3810
[2026-07-15 09:41:56.367] [192.168.1.64] I (473463) UsSensor: 37.4-0, 37.4-0, 37.5-0, 37.5-0, 37.5-0, 37.5-0, 37.5-0
[2026-07-15 09:41:56.395] [192.168.1.64] I (473483) WaterTankApp: Distance: 37.5 - UsResult 0 | Battery: 3810
[2026-07-15 09:42:02.487] [192.168.1.64] I (479583) UsSensor: 37.4-0, 37.5-0, 37.5-0, 37.5-0, 37.5-0, 37.5-0, 37.5-0
[2026-07-15 09:42:02.527] [192.168.1.64] I (479603) WaterTankApp: Distance: 37.5 - UsResult 0 | Battery: 3810
[2026-07-15 09:42:08.607] [192.168.1.64] I (485703) UsSensor: 38.3-0, 38.4-0, 38.4-0, 38.5-0, 38.4-0, 38.4-0, 38.5-0
[2026-07-15 09:42:08.671] [192.168.1.64] I (485753) WaterTankApp: Distance: 38.4 - UsResult 0 | Battery: 3804
[2026-07-15 09:42:14.757] [192.168.1.64] I (491853) UsSensor: 38.3-0, 38.4-0, 38.4-0, 38.4-0, 38.5-0, 38.5-0, 38.5-0
[2026-07-15 09:42:14.785] [192.168.1.64] I (491873) WaterTankApp: Distance: 38.4 - UsResult 0 | Battery: 3810
[2026-07-15 09:42:20.877] [192.168.1.64] I (497973) UsSensor: 38.0-0, 38.1-0, 38.1-0, 38.1-0, 38.1-0, 38.1-0, 38.1-0
[2026-07-15 09:42:20.906] [192.168.1.64] I (497993) WaterTankApp: Distance: 38.1 - UsResult 0 | Battery: 3810
[2026-07-15 09:42:27.000] [192.168.1.64] I (504093) UsSensor: 38.0-0, 38.1-0, 38.1-0, 38.1-0, 38.1-0, 38.1-0, 38.1-0
[2026-07-15 09:42:27.025] [192.168.1.64] I (504113) WaterTankApp: Distance: 38.1 - UsResult 0 | Battery: 3810
[2026-07-15 09:42:33.117] [192.168.1.64] I (510213) UsSensor: 38.0-0, 38.1-0, 38.1-0, 38.1-0, 38.1-0, 38.1-0, 38.1-0
[2026-07-15 09:42:33.148] [192.168.1.64] I (510233) WaterTankApp: Distance: 38.1 - UsResult 0 | Battery: 3810
[2026-07-15 09:42:39.237] [192.168.1.64] I (516333) UsSensor: 38.0-0, 38.1-0, 38.1-0, 38.1-0, 38.1-0, 38.1-0, 38.1-0
[2026-07-15 09:42:39.265] [192.168.1.64] I (516353) WaterTankApp: Distance: 38.1 - UsResult 0 | Battery: 3810
[2026-07-15 09:42:45.357] [192.168.1.64] I (522453) UsSensor: 38.0-0, 38.1-0, 38.1-0, 38.1-0, 38.1-0, 38.1-0, 38.1-0
[2026-07-15 09:42:45.385] [192.168.1.64] I (522473) WaterTankApp: Distance: 38.1 - UsResult 0 | Battery: 3810
[2026-07-15 09:42:51.477] [192.168.1.64] I (528573) UsSensor: 37.7-0, 37.8-0, 37.8-0, 37.8-0, 37.8-0, 37.8-0, 37.8-0
[2026-07-15 09:42:51.505] [192.168.1.64] I (528593) WaterTankApp: Distance: 37.8 - UsResult 0 | Battery: 3810
[2026-07-15 09:42:57.596] [192.168.1.64] I (534693) UsSensor: 37.7-0, 37.8-0, 37.8-0, 37.7-0, 37.8-0, 37.8-0, 37.8-0
[2026-07-15 09:42:57.625] [192.168.1.64] I (534713) WaterTankApp: Distance: 37.8 - UsResult 0 | Battery: 3810
[2026-07-15 09:43:03.717] [192.168.1.64] I (540813) UsSensor: 37.7-0, 37.8-0, 37.7-0, 37.8-0, 37.8-0, 37.7-0, 37.8-0
[2026-07-15 09:43:03.745] [192.168.1.64] I (540833) WaterTankApp: Distance: 37.8 - UsResult 0 | Battery: 3810
[2026-07-15 09:43:09.836] [192.168.1.64] I (546933) UsSensor: 37.7-0, 37.8-0, 37.8-0, 37.8-0, 37.8-0, 37.8-0, 37.8-0
[2026-07-15 09:43:09.865] [192.168.1.64] I (546953) WaterTankApp: Distance: 37.8 - UsResult 0 | Battery: 3810
[2026-07-15 09:43:15.957] [192.168.1.64] I (553053) UsSensor: 37.7-0, 37.8-0, 37.8-0, 37.8-0, 37.8-0, 37.8-0, 37.8-0
[2026-07-15 09:43:15.985] [192.168.1.64] I (553073) WaterTankApp: Distance: 37.8 - UsResult 0 | Battery: 3810
[2026-07-15 09:43:22.076] [192.168.1.64] I (559173) UsSensor: 37.7-0, 37.8-0, 37.8-0, 37.8-0, 37.8-0, 37.8-0, 37.8-0
[2026-07-15 09:43:22.105] [192.168.1.64] I (559193) WaterTankApp: Distance: 37.8 - UsResult 0 | Battery: 3810
[2026-07-15 09:43:28.196] [192.168.1.64] I (565293) UsSensor: 38.7-0, 37.8-0, 37.8-0, 35.9-0, 37.8-0, 37.8-0, 37.8-0
[2026-07-15 09:43:28.224] [192.168.1.64] I (565313) WaterTankApp: Distance: 37.7 - UsResult 0 | Battery: 3810
[2026-07-15 09:43:34.316] [192.168.1.64] I (571413) UsSensor: 37.4-0, 37.5-0, 37.5-0, 37.5-0, 37.5-0, 37.5-0, 37.5-0
[2026-07-15 09:43:34.344] [192.168.1.64] I (571433) WaterTankApp: Distance: 37.5 - UsResult 0 | Battery: 3810
[2026-07-15 09:43:40.436] [192.168.1.64] I (577533) UsSensor: 38.3-0, 38.4-0, 38.4-0, 38.5-0, 38.4-0, 38.4-0, 38.4-0
[2026-07-15 09:43:40.464] [192.168.1.64] I (577553) WaterTankApp: Distance: 38.4 - UsResult 0 | Battery: 3810
[2026-07-15 09:43:46.556] [192.168.1.64] I (583653) UsSensor: 38.3-0, 38.4-0, 38.4-0, 38.4-0, 38.5-0, 38.4-0, 38.5-0
[2026-07-15 09:43:46.584] [192.168.1.64] I (583673) WaterTankApp: Distance: 38.4 - UsResult 0 | Battery: 3810
[2026-07-15 09:43:52.676] [192.168.1.64] I (589773) UsSensor: 38.3-0, 38.5-0, 38.4-0, 38.5-0, 38.5-0, 38.5-0, 38.4-0
[2026-07-15 09:43:52.709] [192.168.1.64] I (589793) WaterTankApp: Distance: 38.4 - UsResult 0 | Battery: 3810
[2026-07-15 09:43:58.796] [192.168.1.64] I (595893) UsSensor: 38.3-0, 38.4-0, 38.4-0, 38.5-0, 38.4-0, 38.4-0, 38.4-0
[2026-07-15 09:43:58.824] [192.168.1.64] I (595913) WaterTankApp: Distance: 38.4 - UsResult 0 | Battery: 3810
[2026-07-15 09:44:04.916] [192.168.1.64] I (602013) UsSensor: 38.3-0, 38.4-0, 38.4-0, 38.4-0, 38.4-0, 38.5-0, 38.4-0
[2026-07-15 09:44:04.944] [192.168.1.64] I (602033) WaterTankApp: Distance: 38.4 - UsResult 0 | Battery: 3810
[2026-07-15 09:44:11.038] [192.168.1.64] I (608133) UsSensor: 38.3-0, 38.4-0, 38.4-0, 38.4-0, 38.4-0, 38.5-0, 38.4-0
[2026-07-15 09:44:11.071] [192.168.1.64] I (608153) WaterTankApp: Distance: 38.4 - UsResult 0 | Battery: 3810
[2026-07-15 09:44:17.156] [192.168.1.64] I (614253) UsSensor: 38.3-0, 38.4-0, 38.4-0, 38.4-0, 38.4-0, 38.5-0, 38.4-0
[2026-07-15 09:44:17.184] [192.168.1.64] I (614273) WaterTankApp: Distance: 38.4 - UsResult 0 | Battery: 3810
[2026-07-15 09:44:23.276] [192.168.1.64] I (620373) UsSensor: 38.3-0, 38.4-0, 38.4-0, 38.4-0, 38.4-0, 38.4-0, 38.4-0
[2026-07-15 09:44:23.304] [192.168.1.64] I (620393) WaterTankApp: Distance: 38.4 - UsResult 0 | Battery: 3810
[2026-07-15 09:44:29.398] [192.168.1.64] I (626493) UsSensor: 38.3-0, 38.5-0, 38.4-0, 38.4-0, 38.4-0, 38.4-0, 38.4-0
[2026-07-15 09:44:29.424] [192.168.1.64] I (626513) WaterTankApp: Distance: 38.4 - UsResult 0 | Battery: 3810
[2026-07-15 09:44:35.516] [192.168.1.64] I (632613) UsSensor: 38.3-0, 38.4-0, 38.4-0, 38.4-0, 38.5-0, 38.4-0, 38.4-0
[2026-07-15 09:44:35.544] [192.168.1.64] I (632633) WaterTankApp: Distance: 38.4 - UsResult 0 | Battery: 3810
[2026-07-15 09:44:41.636] [192.168.1.64] I (638733) UsSensor: 38.3-0, 38.4-0, 38.5-0, 38.4-0, 38.4-0, 38.4-0, 38.4-0
[2026-07-15 09:44:41.665] [192.168.1.64] I (638753) WaterTankApp: Distance: 38.4 - UsResult 0 | Battery: 3810
[2026-07-15 09:44:47.756] [192.168.1.64] I (644853) UsSensor: 38.3-0, 38.4-0, 38.4-0, 38.4-0, 38.4-0, 38.4-0, 38.4-0
[2026-07-15 09:44:47.784] [192.168.1.64] I (644873) WaterTankApp: Distance: 38.4 - UsResult 0 | Battery: 3810
[2026-07-15 09:44:53.876] [192.168.1.64] I (650973) UsSensor: 38.4-0, 38.5-0, 38.4-0, 38.4-0, 38.4-0, 38.4-0, 38.4-0
[2026-07-15 09:44:53.904] [192.168.1.64] I (650993) WaterTankApp: Distance: 38.4 - UsResult 0 | Battery: 3810
[2026-07-15 09:44:59.998] [192.168.1.64] I (657093) UsSensor: 38.3-0, 38.4-0, 38.5-0, 38.4-0, 38.4-0, 38.4-0, 38.5-0
[2026-07-15 09:45:00.060] [192.168.1.64] I (657143) WaterTankApp: Distance: 38.4 - UsResult 0 | Battery: 3804
[2026-07-15 09:45:06.153] [192.168.1.64] I (663243) UsSensor: 38.3-0, 38.4-0, 38.4-0, 38.4-0, 38.4-0, 38.4-0, 38.4-0
[2026-07-15 09:45:06.174] [192.168.1.64] I (663263) WaterTankApp: Distance: 38.4 - UsResult 0 | Battery: 3810
[2026-07-15 09:45:12.274] [192.168.1.64] I (669363) UsSensor: 38.3-0, 38.4-0, 38.5-0, 38.4-0, 38.4-0, 38.4-0, 38.5-0
[2026-07-15 09:45:12.294] [192.168.1.64] I (669383) WaterTankApp: Distance: 38.4 - UsResult 0 | Battery: 3810
[2026-07-15 09:45:18.385] [192.168.1.64] I (675483) UsSensor: 38.3-0, 38.4-0, 38.4-0, 38.4-0, 38.4-0, 38.4-0, 38.4-0
[2026-07-15 09:45:18.417] [192.168.1.64] I (675503) WaterTankApp: Distance: 38.4 - UsResult 0 | Battery: 3810
[2026-07-15 09:45:24.505] [192.168.1.64] I (681603) UsSensor: 38.4-0, 38.4-0, 38.4-0, 38.5-0, 38.4-0, 38.4-0, 38.4-0
[2026-07-15 09:45:24.533] [192.168.1.64] I (681623) WaterTankApp: Distance: 38.4 - UsResult 0 | Battery: 3810
[2026-07-15 09:45:30.625] [192.168.1.64] I (687723) UsSensor: 38.3-0, 38.4-0, 38.4-0, 38.4-0, 38.4-0, 38.4-0, 38.4-0
[2026-07-15 09:45:30.653] [192.168.1.64] I (687743) WaterTankApp: Distance: 38.4 - UsResult 0 | Battery: 3810
[2026-07-15 09:45:36.747] [192.168.1.64] I (693843) UsSensor: 38.3-0, 38.4-0, 38.4-0, 38.4-0, 38.4-0, 38.4-0, 38.4-0
[2026-07-15 09:45:36.773] [192.168.1.64] I (693863) WaterTankApp: Distance: 38.4 - UsResult 0 | Battery: 3810
[2026-07-15 09:45:42.865] [192.168.1.64] I (699963) UsSensor: 38.3-0, 38.4-0, 38.4-0, 38.4-0, 38.4-0, 38.4-0, 38.4-0
[2026-07-15 09:45:42.894] [192.168.1.64] I (699983) WaterTankApp: Distance: 38.4 - UsResult 0 | Battery: 3810
[2026-07-15 09:45:48.989] [192.168.1.64] I (706083) UsSensor: 38.3-0, 38.4-0, 38.4-0, 38.4-0, 38.4-0, 38.5-0, 38.4-0
[2026-07-15 09:45:49.016] [192.168.1.64] I (706103) WaterTankApp: Distance: 38.4 - UsResult 0 | Battery: 3810
[2026-07-15 09:45:55.105] [192.168.1.64] I (712203) UsSensor: 38.3-0, 38.4-0, 38.4-0, 38.5-0, 38.4-0, 38.4-0, 38.4-0
[2026-07-15 09:45:55.133] [192.168.1.64] I (712223) WaterTankApp: Distance: 38.4 - UsResult 0 | Battery: 3810
[2026-07-15 09:46:01.225] [192.168.1.64] I (718323) UsSensor: 38.3-0, 38.4-0, 38.4-0, 38.4-0, 38.4-0, 38.4-0, 38.4-0
[2026-07-15 09:46:01.253] [192.168.1.64] I (718343) WaterTankApp: Distance: 38.4 - UsResult 0 | Battery: 3810
[2026-07-15 09:46:07.345] [192.168.1.64] I (724443) UsSensor: 38.3-0, 38.4-0, 38.4-0, 38.4-0, 38.4-0, 38.5-0, 38.4-0
[2026-07-15 09:46:07.373] [192.168.1.64] I (724463) WaterTankApp: Distance: 38.4 - UsResult 0 | Battery: 3810
[2026-07-15 09:46:13.465] [192.168.1.64] I (730563) UsSensor: 38.3-0, 38.5-0, 38.4-0, 38.4-0, 38.5-0, 38.4-0, 38.4-0
[2026-07-15 09:46:13.493] [192.168.1.64] I (730583) WaterTankApp: Distance: 38.4 - UsResult 0 | Battery: 3810
[2026-07-15 09:46:19.585] [192.168.1.64] I (736683) UsSensor: 38.3-0, 38.4-0, 38.4-0, 38.5-0, 38.4-0, 38.4-0, 38.4-0
[2026-07-15 09:46:19.613] [192.168.1.64] I (736703) WaterTankApp: Distance: 38.4 - UsResult 0 | Battery: 3810
[2026-07-15 09:46:25.711] [192.168.1.64] I (742803) UsSensor: 38.3-0, 38.4-0, 38.4-0, 38.4-0, 38.4-0, 38.4-0, 38.4-0
[2026-07-15 09:46:25.733] [192.168.1.64] I (742823) WaterTankApp: Distance: 38.4 - UsResult 0 | Battery: 3810
[2026-07-15 09:46:31.825] [192.168.1.64] I (748923) UsSensor: 38.3-0, 38.4-0, 38.4-0, 38.4-0, 38.4-0, 38.4-0, 38.4-0
[2026-07-15 09:46:31.853] [192.168.1.64] I (748943) WaterTankApp: Distance: 38.4 - UsResult 0 | Battery: 3810
[2026-07-15 09:46:37.950] [192.168.1.64] I (755043) UsSensor: 38.3-0, 38.4-0, 38.4-0, 38.4-0, 38.4-0, 38.4-0, 38.4-0
[2026-07-15 09:46:37.982] [192.168.1.64] I (755063) WaterTankApp: Distance: 38.4 - UsResult 0 | Battery: 3810
[2026-07-15 09:46:44.071] [192.168.1.64] I (761163) UsSensor: 38.3-0, 38.4-0, 38.4-0, 38.4-0, 38.4-0, 38.4-0, 38.4-0
[2026-07-15 09:46:44.097] [192.168.1.64] I (761183) WaterTankApp: Distance: 38.4 - UsResult 0 | Battery: 3810
[2026-07-15 09:46:50.185] [192.168.1.64] I (767283) UsSensor: 38.3-0, 38.1-0, 38.5-0, 38.4-0, 38.4-0, 38.4-0, 38.4-0
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

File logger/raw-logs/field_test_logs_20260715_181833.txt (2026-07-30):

[2026-07-15 18:22:30.433] [192.168.1.64] I (6230) esp_netif_handlers: sta ip: 192.168.1.64, mask: 255.255.255.0, gw: 192.168.1.1
[2026-07-15 18:22:31.058] [192.168.1.64] <ba-add>idx:0 (ifx:0, 3e:4e:05:24:7d:3b), tid:5, ssn:6, winSize:64
[2026-07-15 18:22:31.058] [192.168.1.64] 
[2026-07-15 18:22:32.087] [192.168.1.64] I (8200) UsSensor: 39.7-0, 40.4-0, 40.1-0, 40.1-0, 40.1-0, 40.1-0, 40.4-0
[2026-07-15 18:22:32.112] [192.168.1.64] I (8220) WaterTankApp: Distance: 40.1 - UsResult 0 | Battery: 3778
[2026-07-15 18:22:38.204] [192.168.1.64] I (14320) UsSensor: 39.9-0, 40.1-0, 40.1-0, 40.1-0, 40.4-0, 40.4-0, 39.4-0
[2026-07-15 18:22:38.233] [192.168.1.64] I (14340) WaterTankApp: Distance: 40.1 - UsResult 0 | Battery: 3780
[2026-07-15 18:22:44.324] [192.168.1.64] I (20440) UsSensor: 40.3-0, 40.4-0, 40.4-0, 40.4-0, 40.4-0, 40.4-0, 40.4-0
[2026-07-15 18:22:44.358] [192.168.1.64] I (20460) WaterTankApp: Distance: 40.4 - UsResult 0 | Battery: 3780
[2026-07-15 18:22:50.444] [192.168.1.64] I (26560) UsSensor: 40.3-0, 40.4-0, 40.4-0, 40.4-0, 39.4-0, 39.4-0, 39.4-0
[2026-07-15 18:22:50.472] [192.168.1.64] I (26580) WaterTankApp: Distance: 40.0 - UsResult 0 | Battery: 3780
[2026-07-15 18:22:56.564] [192.168.1.64] I (32680) UsSensor: 40.0-0, 40.1-0, 40.4-0, 40.7-0, 40.4-0, 40.4-0, 40.1-0
[2026-07-15 18:22:56.592] [192.168.1.64] I (32700) WaterTankApp: Distance: 40.3 - UsResult 0 | Battery: 3780
[2026-07-15 18:23:02.688] [192.168.1.64] I (38800) UsSensor: 40.0-0, 40.1-0, 40.0-0, 40.0-0, 40.4-0, 40.4-0, 39.4-0
[2026-07-15 18:23:02.712] [192.168.1.64] I (38820) WaterTankApp: Distance: 40.1 - UsResult 0 | Battery: 3778
[2026-07-15 18:23:08.804] [192.168.1.64] I (44920) UsSensor: 40.3-0, 40.4-0, 40.4-0, 40.4-0, 40.0-0, 40.0-0, 40.1-0
[2026-07-15 18:23:08.863] [192.168.1.64] I (44970) WaterTankApp: Distance: 40.2 - UsResult 0 | Battery: 3772
[2026-07-15 18:23:14.954] [192.168.1.64] I (51070) UsSensor: 40.9-0, 41.0-0, 41.0-0, 40.1-0, 40.0-0, 40.1-0, 40.0-0
[2026-07-15 18:23:14.984] [192.168.1.64] I (51090) WaterTankApp: Distance: 40.4 - UsResult 0 | Battery: 3774
[2026-07-15 18:23:21.074] [192.168.1.64] I (57190) UsSensor: 40.0-0, 40.0-0, 40.1-0, 40.1-0, 40.0-0, 40.1-0, 40.4-0
[2026-07-15 18:23:21.102] [192.168.1.64] I (57210) WaterTankApp: Distance: 40.1 - UsResult 0 | Battery: 3774
[2026-07-15 18:23:27.194] [192.168.1.64] I (63310) UsSensor: 39.3-0, 40.7-0, 39.4-0, 40.4-0, 40.4-0, 40.1-0, 40.1-0
[2026-07-15 18:23:27.222] [192.168.1.64] I (63330) WaterTankApp: Distance: 40.1 - UsResult 0 | Battery: 3772
[2026-07-15 18:23:33.314] [192.168.1.64] I (69430) UsSensor: 40.3-0, 40.1-0, 40.1-0, 40.0-0, 40.4-0, 40.4-0, 40.4-0
[2026-07-15 18:23:33.342] [192.168.1.64] I (69450) WaterTankApp: Distance: 40.2 - UsResult 0 | Battery: 3778
[2026-07-15 18:23:39.434] [192.168.1.64] I (75550) UsSensor: 40.3-0, 40.4-0, 40.4-0, 40.4-0, 40.4-0, 40.4-0, 40.4-0
[2026-07-15 18:23:39.462] [192.168.1.64] I (75570) WaterTankApp: Distance: 40.4 - UsResult 0 | Battery: 3774
[2026-07-15 18:23:45.554] [192.168.1.64] I (81670) UsSensor: 40.0-0, 40.3-0, 40.4-0, 40.4-0, 40.4-0, 40.1-0, 40.1-0
[2026-07-15 18:23:45.582] [192.168.1.64] I (81690) WaterTankApp: Distance: 40.2 - UsResult 0 | Battery: 3776
[2026-07-15 18:23:51.674] [192.168.1.64] I (87790) UsSensor: 40.0-0, 40.7-0, 40.7-0, 41.0-0, 40.1-0, 40.0-0, 40.4-0
[2026-07-15 18:23:51.702] [192.168.1.64] I (87810) WaterTankApp: Distance: 40.4 - UsResult 0 | Battery: 3772
[2026-07-15 18:23:57.794] [192.168.1.64] I (93910) UsSensor: 40.0-0, 40.1-0, 40.4-0, 40.4-0, 40.1-0, 40.1-0, 40.0-0
[2026-07-15 18:23:57.822] [192.168.1.64] I (93930) WaterTankApp: Distance: 40.2 - UsResult 0 | Battery: 3776
[2026-07-15 18:24:03.914] [192.168.1.64] I (100030) UsSensor: 40.0-0, 40.4-0, 40.1-0, 40.0-0, 40.0-0, 40.1-0, 40.1-0
[2026-07-15 18:24:03.942] [192.168.1.64] I (100050) WaterTankApp: Distance: 40.1 - UsResult 0 | Battery: 3774
[2026-07-15 18:24:10.034] [192.168.1.64] I (106150) UsSensor: 40.3-0, 40.1-0, 40.1-0, 40.1-0, 40.1-0, 40.0-0, 40.4-0
[2026-07-15 18:24:10.068] [192.168.1.64] I (106170) WaterTankApp: Distance: 40.1 - UsResult 0 | Battery: 3776
[2026-07-15 18:24:16.154] [192.168.1.64] I (112270) UsSensor: 40.0-0, 40.4-0, 40.4-0, 40.4-0, 40.4-0, 40.4-0, 40.1-0
[2026-07-15 18:24:16.182] [192.168.1.64] I (112290) WaterTankApp: Distance: 40.3 - UsResult 0 | Battery: 3778
[2026-07-15 18:24:22.274] [192.168.1.64] I (118390) UsSensor: 40.0-0, 40.0-0, 40.1-0, 40.1-0, 40.0-0, 40.1-0, 40.1-0
[2026-07-15 18:24:22.302] [192.168.1.64] I (118410) WaterTankApp: Distance: 40.0 - UsResult 0 | Battery: 3776
[2026-07-15 18:24:28.398] [192.168.1.64] I (124510) UsSensor: 40.0-0, 41.0-0, 41.0-0, 40.1-0, 40.0-0, 40.1-0, 40.1-0
[2026-07-15 18:24:28.422] [192.168.1.64] I (124530) WaterTankApp: Distance: 40.3 - UsResult 0 | Battery: 3778
[2026-07-15 18:24:34.514] [192.168.1.64] I (130630) UsSensor: 40.9-0, 41.0-0, 40.1-0, 40.1-0, 40.1-0, 40.0-0, 40.0-0
[2026-07-15 18:24:34.542] [192.168.1.64] I (130650) WaterTankApp: Distance: 40.3 - UsResult 0 | Battery: 3774
[2026-07-15 18:24:40.634] [192.168.1.64] I (136750) UsSensor: 40.0-0, 40.1-0, 41.0-0, 40.7-0, 40.7-0, 40.7-0, 41.0-0
[2026-07-15 18:24:40.662] [192.168.1.64] I (136770) WaterTankApp: Distance: 40.6 - UsResult 0 | Battery: 3774
[2026-07-15 18:24:46.754] [192.168.1.64] I (142870) UsSensor: 40.0-0, 40.1-0, 40.1-0, 40.1-0, 40.1-0, 40.1-0, 40.0-0
[2026-07-15 18:24:46.782] [192.168.1.64] I (142890) WaterTankApp: Distance: 40.1 - UsResult 0 | Battery: 3772
[2026-07-15 18:24:52.874] [192.168.1.64] I (148990) UsSensor: 40.0-0, 40.0-0, 40.0-0, 40.1-0, 40.0-0, 40.1-0, 40.0-0
[2026-07-15 18:24:52.902] [192.168.1.64] I (149010) WaterTankApp: Distance: 40.0 - UsResult 0 | Battery: 3776
[2026-07-15 18:24:58.994] [192.168.1.64] I (155110) UsSensor: 40.0-0, 40.1-0, 40.1-0, 41.0-0, 41.0-0, 41.0-0, 40.1-0
[2026-07-15 18:24:59.024] [192.168.1.64] I (155130) WaterTankApp: Distance: 40.5 - UsResult 0 | Battery: 3780
[2026-07-15 18:25:05.114] [192.168.1.64] I (161230) UsSensor: 40.6-0, 40.7-0, 40.1-0, 40.1-0, 40.1-0, 40.1-0, 40.1-0
[2026-07-15 18:25:05.142] [192.168.1.64] I (161250) WaterTankApp: Distance: 40.2 - UsResult 0 | Battery: 3778
[2026-07-15 18:25:11.234] [192.168.1.64] I (167350) UsSensor: 40.0-0, 40.1-0, 40.1-0, 41.0-0, 41.0-0, 40.1-0, 40.0-0
[2026-07-15 18:25:11.263] [192.168.1.64] I (167370) WaterTankApp: Distance: 40.3 - UsResult 0 | Battery: 3776
[2026-07-15 18:25:17.355] [192.168.1.64] I (173470) UsSensor: 40.0-0, 40.1-0, 40.0-0, 40.1-0, 41.0-0, 41.0-0, 41.0-0
[2026-07-15 18:25:17.382] [192.168.1.64] I (173490) WaterTankApp: Distance: 40.5 - UsResult 0 | Battery: 3778
[2026-07-15 18:25:23.475] [192.168.1.64] I (179590) UsSensor: 40.9-0, 40.1-0, 40.0-0, 40.1-0, 40.0-0, 40.1-0, 40.0-0
[2026-07-15 18:25:23.502] [192.168.1.64] I (179610) WaterTankApp: Distance: 40.2 - UsResult 0 | Battery: 3780
[2026-07-15 18:25:29.594] [192.168.1.64] I (185710) UsSensor: 40.0-0, 40.1-0, 40.1-0, 40.1-0, 40.1-0, 41.0-0, 40.1-0
[2026-07-15 18:25:29.622] [192.168.1.64] I (185730) WaterTankApp: Distance: 40.2 - UsResult 0 | Battery: 3776
[2026-07-15 18:25:35.714] [192.168.1.64] I (191830) UsSensor: 40.0-0, 40.1-0, 40.1-0, 40.0-0, 40.1-0, 40.1-0, 40.1-0
[2026-07-15 18:25:35.742] [192.168.1.64] I (191850) WaterTankApp: Distance: 40.1 - UsResult 0 | Battery: 3774
[2026-07-15 18:25:41.834] [192.168.1.64] I (197950) UsSensor: 40.9-0, 41.0-0, 41.0-0, 40.1-0, 40.1-0, 40.1-0, 40.1-0
[2026-07-15 18:25:41.862] [192.168.1.64] I (197970) WaterTankApp: Distance: 40.5 - UsResult 0 | Battery: 3776
[2026-07-15 18:25:47.954] [192.168.1.64] I (204070) UsSensor: 40.0-0, 40.1-0, 40.0-0, 40.1-0, 44.1-0, 41.0-0, 40.7-0
[2026-07-15 18:25:47.982] [192.168.1.64] I (204090) WaterTankApp: Distance: 40.9 - UsResult 0 | Battery: 3772
[2026-07-15 18:25:54.075] [192.168.1.64] I (210190) UsSensor: 40.9-0, 40.7-0, 40.7-0, 41.0-0, 41.0-0, 41.0-0, 40.1-0
[2026-07-15 18:25:54.108] [192.168.1.64] I (210210) WaterTankApp: Distance: 40.8 - UsResult 0 | Battery: 3780
[2026-07-15 18:26:00.194] [192.168.1.64] I (216310) UsSensor: 40.0-0, 40.1-0, 40.0-0, 40.1-0, 41.0-0, 41.0-0, 41.0-0
[2026-07-15 18:26:00.252] [192.168.1.64] I (216360) WaterTankApp: Distance: 40.5 - UsResult 0 | Battery: 3772
[2026-07-15 18:26:06.344] [192.168.1.64] I (222460) UsSensor: 40.0-0, 40.1-0, 40.1-0, 40.1-0, 40.1-0, 40.0-0, 41.0-0
[2026-07-15 18:26:06.372] [192.168.1.64] I (222480) WaterTankApp: Distance: 40.2 - UsResult 0 | Battery: 3778
[2026-07-15 18:26:12.464] [192.168.1.64] I (228580) UsSensor: 40.9-0, 41.0-0, 41.0-0, 40.1-0, 40.0-0, 40.1-0, 40.1-0
[2026-07-15 18:26:12.492] [192.168.1.64] I (228600) WaterTankApp: Distance: 40.4 - UsResult 0 | Battery: 3776
[2026-07-15 18:26:18.584] [192.168.1.64] I (234700) UsSensor: 40.0-0, 40.1-0, 40.1-0, 40.1-0, 40.0-0, 41.0-0, 41.0-0
[2026-07-15 18:26:18.612] [192.168.1.64] I (234720) WaterTankApp: Distance: 40.3 - UsResult 0 | Battery: 3774
[2026-07-15 18:26:24.704] [192.168.1.64] I (240820) UsSensor: 40.9-0, 41.0-0, 40.9-0, 41.0-0, 41.0-0, 40.1-0, 40.1-0
[2026-07-15 18:26:24.737] [192.168.1.64] I (240840) WaterTankApp: Distance: 40.7 - UsResult 0 | Battery: 3778
[2026-07-15 18:26:30.824] [192.168.1.64] I (246940) UsSensor: 40.9-0, 41.0-0, 41.0-0, 41.0-0, 41.0-0, 41.0-0, 40.1-0
[2026-07-15 18:26:30.852] [192.168.1.64] I (246960) WaterTankApp: Distance: 40.9 - UsResult 0 | Battery: 3780
[2026-07-15 18:26:36.944] [192.168.1.64] I (253060) UsSensor: 40.0-0, 40.1-0, 40.1-0, 40.0-0, 41.0-0, 41.0-0, 41.0-0
[2026-07-15 18:26:36.972] [192.168.1.64] I (253080) WaterTankApp: Distance: 40.5 - UsResult 0 | Battery: 3772
[2026-07-15 18:26:43.065] [192.168.1.64] I (259180) UsSensor: 40.0-0, 41.0-0, 41.0-0, 41.0-0, 41.0-0, 40.1-0, 40.1-0
[2026-07-15 18:26:43.094] [192.168.1.64] I (259200) WaterTankApp: Distance: 40.6 - UsResult 0 | Battery: 3776
[2026-07-15 18:26:49.184] [192.168.1.64] I (265300) UsSensor: 40.0-0, 40.1-0, 40.1-0, 40.1-0, 40.1-0, 40.0-0, 40.0-0
[2026-07-15 18:26:49.212] [192.168.1.64] I (265320) WaterTankApp: Distance: 40.1 - UsResult 0 | Battery: 3780
[2026-07-15 18:26:55.304] [192.168.1.64] I (271420) UsSensor: 40.0-0, 40.1-0, 40.0-0, 40.1-0, 40.0-0, 40.1-0, 40.1-0
[2026-07-15 18:26:55.332] [192.168.1.64] I (271440) WaterTankApp: Distance: 40.1 - UsResult 0 | Battery: 3776
[2026-07-15 18:27:01.425] [192.168.1.64] I (277540) UsSensor: 40.9-0, 41.0-0, 41.0-0, 41.0-0, 41.0-0, 41.0-0, 40.1-0
[2026-07-15 18:27:01.452] [192.168.1.64] I (277560) WaterTankApp: Distance: 40.9 - UsResult 0 | Battery: 3776
[2026-07-15 18:27:07.544] [192.168.1.64] I (283660) UsSensor: 40.9-0, 41.0-0, 41.0-0, 40.0-0, 40.1-0, 40.1-0, 40.1-0
[2026-07-15 18:27:07.572] [192.168.1.64] I (283680) WaterTankApp: Distance: 40.5 - UsResult 0 | Battery: 3774
[2026-07-15 18:27:13.664] [192.168.1.64] I (289780) UsSensor: 40.0-0, 40.1-0, 41.0-0, 41.0-0, 41.0-0, 41.0-0, 41.0-0
[2026-07-15 18:27:13.692] [192.168.1.64] I (289800) WaterTankApp: Distance: 40.7 - UsResult 0 | Battery: 3774
[2026-07-15 18:27:19.784] [192.168.1.64] I (295900) UsSensor: 40.0-0, 40.1-0, 40.0-0, 37.0-0, 40.1-0, 41.0-0, 41.0-0
[2026-07-15 18:27:19.817] [192.168.1.64] I (295920) WaterTankApp: Distance: 39.9 - UsResult 0 | Battery: 3774
[2026-07-15 18:27:25.904] [192.168.1.64] I (302020) UsSensor: 40.0-0, 40.1-0, 40.0-0, 40.1-0, 40.0-0, 40.1-0, 40.0-0
[2026-07-15 18:27:25.932] [192.168.1.64] I (302040) WaterTankApp: Distance: 40.0 - UsResult 0 | Battery: 3772
[2026-07-15 18:27:32.024] [192.168.1.64] I (308140) UsSensor: 40.0-0, 40.1-0, 40.1-0, 40.0-0, 40.1-0, 40.1-0, 40.0-0
[2026-07-15 18:27:32.052] [192.168.1.64] I (308160) WaterTankApp: Distance: 40.1 - UsResult 0 | Battery: 3774
[2026-07-15 18:27:38.146] [192.168.1.64] I (314260) UsSensor: 40.6-0, 41.0-0, 41.0-0, 40.1-0, 40.1-0, 40.1-0, 40.1-0
[2026-07-15 18:27:38.172] [192.168.1.64] I (314280) WaterTankApp: Distance: 40.4 - UsResult 0 | Battery: 3776
[2026-07-15 18:27:44.263] [192.168.1.64] I (320380) UsSensor: 40.9-0, 41.0-0, 41.0-0, 41.0-0, 41.0-0, 41.0-0, 41.0-0
[2026-07-15 18:27:44.292] [192.168.1.64] I (320400) WaterTankApp: Distance: 41.0 - UsResult 0 | Battery: 3774
[2026-07-15 18:27:50.384] [192.168.1.64] I (326500) UsSensor: 40.9-0, 41.0-0, 41.0-0, 41.0-0, 40.7-0, 40.7-0, 40.7-0
[2026-07-15 18:27:50.412] [192.168.1.64] I (326520) WaterTankApp: Distance: 40.9 - UsResult 0 | Battery: 3774
[2026-07-15 18:27:56.503] [192.168.1.64] I (332620) UsSensor: 40.6-0, 40.7-0, 41.0-0, 41.0-0, 41.0-0, 41.0-0, 41.0-0
[2026-07-15 18:27:56.532] [192.168.1.64] I (332640) WaterTankApp: Distance: 40.9 - UsResult 0 | Battery: 3774
[2026-07-15 18:28:02.623] [192.168.1.64] I (338740) UsSensor: 40.0-0, 40.1-0, 41.0-0, 41.0-0, 41.0-0, 40.7-0, 40.7-0
[2026-07-15 18:28:02.652] [192.168.1.64] I (338760) WaterTankApp: Distance: 40.6 - UsResult 0 | Battery: 3772
[2026-07-15 18:28:08.743] [192.168.1.64] I (344860) UsSensor: 40.9-0, 41.0-0, 41.0-0, 41.0-0, 40.1-0, 41.0-0, 41.0-0
[2026-07-15 18:28:08.772] [192.168.1.64] I (344880) WaterTankApp: Distance: 40.9 - UsResult 0 | Battery: 3774
[2026-07-15 18:28:14.863] [192.168.1.64] I (350980) UsSensor: 40.6-0, 40.7-0, 41.0-0, 41.0-0, 41.0-0, 40.9-0, 35.7-0
[2026-07-15 18:28:14.892] [192.168.1.64] I (351000) WaterTankApp: Distance: 40.9 - UsResult 0 | Battery: 3776
[2026-07-15 18:28:20.983] [192.168.1.64] I (357100) UsSensor: 40.9-0, 41.0-0, 41.0-0, 41.0-0, 41.0-0, 40.7-0, 40.7-0
[2026-07-15 18:28:21.012] [192.168.1.64] I (357120) WaterTankApp: Distance: 40.9 - UsResult 0 | Battery: 3772
[2026-07-15 18:28:27.105] [192.168.1.64] I (363220) UsSensor: 40.6-0, 40.7-0, 40.7-0, 40.7-0, 41.0-0, 41.0-0, 41.0-0
[2026-07-15 18:28:27.132] [192.168.1.64] I (363240) WaterTankApp: Distance: 40.8 - UsResult 0 | Battery: 3774
[2026-07-15 18:28:33.223] [192.168.1.64] I (369340) UsSensor: 40.9-0, 41.0-0, 40.7-0, 40.7-0, 40.7-0, 40.7-0, 40.7-0
[2026-07-15 18:28:33.252] [192.168.1.64] I (369360) WaterTankApp: Distance: 40.8 - UsResult 0 | Battery: 3774
[2026-07-15 18:28:39.345] [192.168.1.64] I (375460) UsSensor: 40.9-0, 41.0-0, 41.0-0, 41.0-0, 40.7-0, 40.7-0, 40.7-0
[2026-07-15 18:28:39.372] [192.168.1.64] I (375480) WaterTankApp: Distance: 40.9 - UsResult 0 | Battery: 3774
[2026-07-15 18:28:45.463] [192.168.1.64] I (381580) UsSensor: 40.6-0, 40.7-0, 40.7-0, 40.7-0, 40.7-0, 40.7-0, 40.7-0
[2026-07-15 18:28:45.492] [192.168.1.64] I (381600) WaterTankApp: Distance: 40.7 - UsResult 0 | Battery: 3774
[2026-07-15 18:28:51.583] [192.168.1.64] I (387700) UsSensor: 40.6-0, 40.7-0, 40.7-0, 40.7-0, 40.7-0, 40.7-0, 40.7-0
[2026-07-15 18:28:51.643] [192.168.1.64] I (387750) WaterTankApp: Distance: 40.7 - UsResult 0 | Battery: 3762
[2026-07-15 18:28:57.734] [192.168.1.64] I (393850) UsSensor: 40.6-0, 40.7-0, 40.7-0, 40.7-0, 40.7-0, 40.7-0, 40.7-0
[2026-07-15 18:28:57.762] [192.168.1.64] I (393870) WaterTankApp: Distance: 40.7 - UsResult 0 | Battery: 3772
[2026-07-15 18:29:03.855] [192.168.1.64] I (399970) UsSensor: 40.3-0, 40.4-0, 40.4-0, 40.7-0, 40.7-0, 40.7-0, 40.7-0
[2026-07-15 18:29:03.882] [192.168.1.64] I (399990) WaterTankApp: Distance: 40.6 - UsResult 0 | Battery: 3772
[2026-07-15 18:29:09.973] [192.168.1.64] I (406090) UsSensor: 40.3-0, 40.4-0, 40.4-0, 40.4-0, 40.4-0, 40.4-0, 40.4-0
[2026-07-15 18:29:10.002] [192.168.1.64] I (406110) WaterTankApp: Distance: 40.4 - UsResult 0 | Battery: 3774
[2026-07-15 18:29:16.093] [192.168.1.64] I (412210) UsSensor: 40.3-0, 40.4-0, 40.4-0, 40.4-0, 40.4-0, 40.4-0, 40.4-0
[2026-07-15 18:29:16.121] [192.168.1.64] I (412230) WaterTankApp: Distance: 40.4 - UsResult 0 | Battery: 3772
[2026-07-15 18:29:22.213] [192.168.1.64] I (418330) UsSensor: 40.3-0, 40.4-0, 40.4-0, 40.4-0, 40.4-0, 40.4-0, 40.4-0
[2026-07-15 18:29:22.241] [192.168.1.64] I (418350) WaterTankApp: Distance: 40.4 - UsResult 0 | Battery: 3778
[2026-07-15 18:29:28.333] [192.168.1.64] I (424450) UsSensor: 40.3-0, 40.4-0, 40.4-0, 40.4-0, 40.4-0, 40.4-0, 40.4-0
[2026-07-15 18:29:28.364] [192.168.1.64] I (424470) WaterTankApp: Distance: 40.4 - UsResult 0 | Battery: 3772
[2026-07-15 18:29:34.453] [192.168.1.64] I (430570) UsSensor: 40.3-0, 40.4-0, 40.4-0, 40.4-0, 40.4-0, 40.4-0, 40.4-0
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

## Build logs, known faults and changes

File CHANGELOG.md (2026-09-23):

# Changelog

All notable changes to this project will be documented in this file.

The format is based on [Keep a Changelog](https://keepachangelog.com/en/1.1.0/),
and this project adheres to [Semantic Versioning](https://semver.org/spec/v2.0.0.html).

## [0.4.5] - 2026-09-23

### Changed
- Configured `float_switch_config.wakeup_on` to `WakeupCondition::WHEN_TANK_IS_EMPTY` in `main.cpp` following the physical installation and wiring of the float switch to GPIO 2.
- Bumped firmware version to `0.4.5`.

## [0.4.4] - 2026-09-15

### Fixed
- Replaced `wait_for_comm_ready` with `ensure_communication_ready` implementing active recovery scan retries with `reconnect()` and initial yield delay.
- Ensured synchronous Wi-Fi start on boot with 3000 ms timeout in `init_wifi()`.

### Changed
- Clarified hysteresis and deadband constants (`BACKUP_EXIT_THRESHOLD`) in `WaterTankLogic::update_operation_mode`.
- Updated `espnow_manager` submodule to latest `main` (v1.5.2) with 2 scan attempts per channel and hardware Wi-Fi channel restore on init.

## [0.4.3] - 2026-08-31

### Changed
- New `ota_manager` version, clear notification bits and purge stale cancel bits on start_ota.

## [0.4.2] - 2026-08-29

### Changed
- Refactor WaterTankApp::process_pending_ota to save storage before reboot on successful OTA, rearm btn_trigger after failed OTA.

## [0.4.1] - 2026-08-27

### Added
- Added nighttime adaptive sleep schedule for `STABLE` and full backup states: 15 minutes (`TIMER_STABLE_NIGHT_US`) between 22:00 and 06:00 (`NIGHT_START_HOUR` / `NIGHT_END_HOUR`), preserving 5 minutes during the day and active evening.
- Added pure boolean `is_night` argument in `WaterTankLogic::calculate_sleep_time_us`.
- Added unit test cases for day vs night sleep intervals in `WaterTankLogicTest`.

### Changed
- Bumped firmware version to `0.4.1`.

## [0.4.0] - 2026-08-27

### Added
- Created `IOtaController` interface and concrete `OtaController` component implementing OTA lifecycle operations (initialization, firmware confirmation, polling download worker, rollback handling, and version retrieval).
- Added `MockOtaController` in `host_test/mocks/` and dedicated unit test suite in `host_test/test_ota_controller/` with 13 test cases.
- Added `UDP_LOG_SERVER_IP` and `UDP_LOG_PORT` network configuration definitions to `secrets.example.hpp`.
- Integrated `test_ota_controller` into root `host_test/CMakeLists.txt` for automated CTest and CI execution.

### Changed
- Refactored `WaterTankApp` to inject `IOtaController&` instead of `IOtaManager&`, removing inline OTA polling loops and error code mappings.
- Replaced hardcoded UDP logger IP and port in `WaterTankApp::init` with definitions from `secrets.hpp`.
- Updated `WaterTankAppTest` fixture and all OTA test cases to use `MockOtaController`.
- Bumped firmware version to `0.3.12`.

## [0.3.11] - 2026-08-27

### Added
- Created `ITankCommandHandler` interface and concrete `TankCommandHandler` component with full support for generic transport commands (`START_OTA`, `REBOOT`) and application commands (`SLEEP_OVERRIDE`, `SYNC_TIME`) with acknowledgement handling.
- Added `MockTankCommandHandler` in `host_test/mocks/` and dedicated unit test suite in `host_test/test_tank_command_handler/`.
- Integrated `test_tank_command_handler` into root `host_test/CMakeLists.txt` for automated CTest and CI execution.

### Changed
- Injected `ITankCommandHandler&` into `WaterTankApp`, decoupling command processing and message listening from application business logic.
- Removed legacy inline command processing methods (`listen_for_messages`, `process_command`, `send_cmd_ack`, `sync_time_from_espnow_packet`) from `WaterTankApp`.
- Updated `WaterTankAppTest` fixture and test cases to use `MockTankCommandHandler`.
- Bumped firmware version to `0.3.11`.

## [0.3.10] - 2026-08-21

### Added
- Integrated `ILedController` status LED indicator on GPIO 8 (D8 on Xiao ESP32-C3) providing non-blocking visual feedback patterns (`BOOT_SUCCESS`, `ERROR_BURST`, `PAIRING_MODE`, `TX_PULSE`, `OTA_UPDATING`).
- Dedicated unit tests for status LED patterns and state transitions in `WaterTankAppTest`.
- Root `host_test/CMakeLists.txt` with CTest multi-suite orchestration (`test_water_tank_geometry`, `test_water_tank_logic`, `test_water_tank_app`), `build_all_tests`, `run_all_tests`, and `unified_coverage`.
- GitHub Actions CI workflows for target firmware compilation (`build.yml`) and host unit tests with coverage (`host_test.yml`).
- Automatic fallback from `secrets.example.hpp` to `secrets.hpp` in CMake configurations for CI builds.

### Changed
- Delegated battery percentage and operating state classification directly to `battery_monitor` component (`BatteryChemistry`).
- Replaced manual battery hysteresis state fields in `WaterTankStats` with read-only telemetry logging fields.
- Modularized `host_test` into distinct test suites with shared mock directories and coverage scripts.
- Updated `README.md` and `DESIGN.md` with CI badges, modern architecture diagrams, pinout tables, and comprehensive test documentation.
- Bumped firmware version to `0.3.10`.

## [0.3.9] - 2026-08-17

### Changed
- Refactored `WaterTankNvs` to inherit from the generic `AppStorage<WaterTankStats, Magic, Version>` CRTP base class in `smart-farm-common`, eliminating local NVS boilerplate and implementation files.
- Decoupled domain struct `WaterTankStats` from storage metadata (`magic`, `version`, `crc`), wrapping it automatically with the new `StorageEnvelope` pattern.
- Migrated `CoreStorage` usage in `WaterTankApp` to pure `CoreData` and separated `process_boot_reasons()` from storage initialization.
- Simplified `init_tank_storage()` and `init_core_storage()` logic utilizing `init_app_data()` / `init()` with automatic fallback to defaults.
- Bumped firmware version to `0.3.9`.

## [0.3.0] - 2026-08-06

### Added
- Multi-sample confirmation window (`FILL_STATE_CONFIRMATIONS_REQUIRED = 2`) for `FillState` transitions to filter out single-sample water turbulence noise.
- Persistent candidate state fields (`pending_fill_state`, `pending_state_count`) in `WaterTankStats` (version 2) stored in RTC RAM.
- Graceful peripheral deactivation (`espnow_.deinit()`) before deep sleep and MCU system restarts (`REBOOT` command).
- ACK confirmation helper `send_cmd_ack()` with 100ms task delay before reboot commands.

### Changed
- Refactored `WaterTankApp::process_command()` into clean command `switch` statements.
- Separated `WaterTankApp::run()` logging into modular step-by-step logs (`Aux sensors`, `Ultrasonic reading`, `Tank state`).
- Removed duplicate component error logging in `WaterTankApp::run()`.

## [0.2.0] - 2026-07-12

### Added
- Debounced hardware OTA trigger (`ButtonOtaTrigger`) and network-activated trigger (`EspNowOtaTrigger`).
- Cooperative cancellation in `OtaController::run_fsm()` inner loop that calls `cancel_ota()` upon stop request.
- Binary semaphore synchronization (`task_done_semaphore_`) for graceful task exit and self-deletion.
- Integrated `idf_hals::IHalFreertos` in `WaterTankApp` and `main.cpp` for mockable FreeRTOS primitives.
- Dynamic stop timeout calculation derived from configured FSM timeouts.
- Unit tests verifying triggers, busy states, cancel behavior, and graceful task deletion.
- Included `smart-farm-common` components in `test_water_tank` coverage report.

### Changed
- Refactored `OtaController` to execute as a non-blocking FreeRTOS task.
- Migrated local sleep adapters to the unified `idf_hals::ISleepHAL` dependency.
- Moved GPIO wakeup bit-shifting and mode mapping logic out of the HAL to the application layer.
- Reduced `LISTEN_WINDOW_MS` to 200 ms for optimized battery consumption during active RX.

### Fixed
- Replaced forced task deletion in `OtaController::stop()` to prevent memory leaks and locked driver mutexes.
- Corrected ESP_LOGE macro compile error in FSM watchdog logs.

## [0.1.0] - 2026-07-10

### Added
- Initial version of Smart Farm Water Tank app.
- Main orchestrator (`WaterTankApp`) using run-to-completion pattern.
- Sensor integration: Ultrasonic (level) and FloatSwitch (backup full/empty level).
- Logic module (`WaterTankLogic`) for permille calculations, sleep timer duration, and error state tracking.
- Geometric tank calculation in `TankGeometry` using a lookup table (LUT) for 5 stacked cylinders.
- Battery monitoring integration (`BatteryMonitor`) via ADC with calibration and hysteresis.
- Over-the-Air (OTA) updates support via `OtaController` using the BOOT button as an initial hardware trigger.
- ESP-NOW communication management (`EspNowManager`) configured to transmit to the HUB node.
- NVS persistence support (`WaterTankNvs`) storing operational stats of the node.
- Deep Sleep management (`SleepHAL`) optimizing power consumption based on level stability.
- Sleep HAL GPIO wakeup integration enabling system wakeup triggered by FloatSwitch state transitions.

### Removed
- Unused GPIO wakeup fields from the Water Tank app statistics.

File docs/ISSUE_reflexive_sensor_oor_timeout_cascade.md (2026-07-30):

# Issue: Sensor reflexivo gera cascata `OUT_OF_RANGE → TIMEOUT` em distâncias maiores (~69 cm)

**Status:** Causa raiz física e bug de software identificados — aguardando correção no driver e ajuste mecânico  
**Componente:** `ultrasonic_sensor` (`us_driver.cpp` + config `UsConfig`) + instalação mecânica do sensor reflexivo  
**Contexto:** Levantado durante validação de campo do sensor reflexivo (2026-07-20), testes
comparativos com e sem condensação em 4 momentos distintos do dia.

---

## Contexto da instalação

O sensor ultrassônico está montado **verticalmente** dentro de uma caixinha que se sobressai
da tampa da caixa d'água. Um espelho a 45° redireciona o feixe de som horizontalmente até a
superfície da água:

```
                |\
                | \
             ___|  \
                |   \
         sensor |    \
             ___|     \ espelho 45°
                |      \
                |       \
________________|        \_______________
|               |         \             |
|               |          \            |
|                                       |
|                                       | ← caixinha do sensor (sobressaída da tampa)
|                                       |
|_______________________________________|
               tampa da caixa d'água

               caixa d'água

________________________________________________
                                      água
```

A caixinha serve para afastar o sensor da dead-zone e da umidade direta.  
`SENSOR_OFFSET_CM = 29.5 cm` (offset do sensor em relação ao topo do nível máximo de água).

---

## Resultado dos testes de campo — sensor reflexivo (2026-07-20)

| Horário | Condição | Dist. Média ± StdDev | Range Total | UsResult |
|---|---|---|---|---|
| **17:30** | Quente, sem condensação | 37.33 ± 0.35 cm | 1.7 cm | **100% OK** (294/294) |
| **23:30** | Noite, início de condensação | 51.32 ± 0.35 cm | 1.6 cm | **100% OK** (206/206) |
| **06:41** | Fria (~20°C), condensação provável | 60.01 ± 0.27 cm | 1.4 cm | **100% OK** (297/297) |
| **10:00** | Quente, sem condensação | 69.3 cm (válidos) | — | **88.1% OK, 9.5% OOR, 2.4% Weak** |

**Conclusão sobre condensação:** o sensor reflexivo se mostrou **completamente imune à
condensação** — os 3 primeiros testes (incluindo manhã fria com condensação provável) tiveram
100% de leituras válidas e estabilidade excelente. O sensor antigo em condição equivalente
apresentava desvio padrão de ~4 cm e variação total de até 19.5 cm.

O problema identificado é **exclusivo do teste das 10:00**, quando a distância de medição
aumentou para ~69 cm (caixa d'água mais consumida ao longo do dia de testes).

---

## Causa raiz: Bug no Software (`us_driver.cpp`) + Eco Parasita Físico

### 1. Evidência Estatística Definitiva por Posição no Burst (Log 10:00)

Analisando a posição exata de cada ping dentro da rajada de 7 pings no log das 10:00,
revela-se um deslocamento 1-para-1 perfeito entre `OUT_OF_RANGE (3)` e `TIMEOUT (2)`:

| Posição no Burst | OK (0) | OUT_OF_RANGE (3) | TIMEOUT (2) | WEAK (1) |
|---|---|---|---|---|
| **Ping 1** | 266 | **28** | **0** | 0 |
| **Ping 2** | 262 | 4 | **28** (exatamente os 28 de Ping 1!) | 0 |
| **Ping 3** | 274 | **16** | 4 | 0 |
| **Ping 4** | 263 | 15 | **16** (exatamente os 16 de Ping 3!) | 0 |
| **Ping 5** | 270 | **9** | **15** (exatamente os 15 de Ping 4!) | 0 |
| **Ping 6** | 261 | **24** | **9** (exatamente os 9 de Ping 5!) | 0 |
| **Ping 7** | 255 | 15 | **24** (exatamente os 24 de Ping 6!) | 0 |

**Todo ping $N$ que dá `OUT_OF_RANGE` força o ping $N+1$ a dar `TIMEOUT` 100% das vezes.**

---

### 2. A Descoberta do Bug no Driver (`us_driver.cpp`)

Inspecionando a implementação do driver em `components/ultrasonic_sensor/src/us_driver.cpp`:

```cpp
Reading UsDriver::ping_once(const UsConfig &cfg)
{
    ...
    // 7. Convert to distance
    float cm = (duration_us * SOUND_SPEED_CM_PER_US) / 2.0f;

    if (cm < cfg.min_distance_cm || cm > cfg.max_distance_cm) {
        ESP_LOGD(TAG, "Out of range: %.1f cm (limits: %.1f-%.1f)", cm, cfg.min_distance_cm, cfg.max_distance_cm);
        return {UsResult::OUT_OF_RANGE, 0.0f}; // ← BUG: Retorna imediatamente!
    }

    // Inter-ping delay: applied after every ping so the sensor can reset.
    if (cfg.ping_interval_ms > 0) {
        timer_hal_->delay_ms(cfg.ping_interval_ms); // ← É PULADO quando dá OOR ou TIMEOUT!
    }

    return {UsResult::OK, cm};
}
```

**Mecânica da Falha:**

1. **Ping N** mede ~20.2 cm (eco da parede da caixinha).
2. Como `20.2 cm < 25.0 cm` (`min_distance_cm`), o driver executa a linha 148: `return {UsResult::OUT_OF_RANGE, 0.0f};`.
3. **O `timer_hal_->delay_ms(70)` da linha 154 É COMPLETAMENTE PULADO!**
4. O loop de rajada (`UsSensor::read_distance`) chama `ping_once()` para o **Ping N+1 IMEDIATAMENTE (delay 0 ms)**.
5. Com delay 0 ms, o eco acústico anterior ainda está viajando no ar / pino ECHO ainda ativo / transdutor ressoando.
6. O **Ping N+1** tenta medir e dá `TIMEOUT` (25.000 µs sem borda limpa).
7. Como o `return {UsResult::TIMEOUT, 0.0f};` (linhas 131 e 138) **também pula o `delay_ms(70)`**, a cascata destrói o restante do ciclo!

---

### 3. Comprovação Definitiva com o Log de 15/07 (`2026-07-15-out-of-range-error.txt`)

No log de 15/07 (sensor horizontal), a configuração era `min_distance_cm = 15.0 cm`:

- **O Ping 1 foi exatamente 20.2 cm em 59.3% de todos os 27 ciclos!**
- Como `20.2 cm > 15.0 cm`, o driver considerava o Ping 1 como `UsResult::OK`.
- Como era `OK`, o driver **executava o `delay_ms(70)`** normalmente.
- Como aguardava 70 ms de descanso, o **Ping 2 em diante conseguia medir a água limpadamente em ~53 cm** (ex: Ciclos 22, 23 e 26 do log, onde Ping 1 era 20.2cm e Pings 2–7 eram 52.9–53.4cm `OK`).

Quando alteramos `min_distance_cm` para 25.0 cm, o Ping 1 de 20.2 cm passou a ser classificado como `OUT_OF_RANGE`, disparando o bug de pular o delay de 70 ms e colapsando os pings subsequentes.

---

## Histórico: Comportamento com Sensor Horizontal (2026-07-15)

Antes do ajuste de `min_distance_cm`, o eco parasita da parede (~20.2–20.3 cm) era aceito como **leitura válida silenciosa**:

```
UsSensor: 20.2-0, 20.3-0, 20.3-0, 20.3-0, 20.3-0, 20.3-0, 20.3-0
App: Distance: 20.3 - UsResult 0   ← FALSO POSITIVO SILENCIOSO
```

O eco parasita da parede é **extremamente estável** (stdev = 0.042 cm) — uma superfície rígida fixa. O eco real da água fica em ~52 cm (stdev ~2 cm).

Em ciclos mistos, o `DOMINANT_CLUSTER` nem sempre vencia a favor da água:

| Tipo de ciclo no log 15/07 | Ocorrências | Resultado App |
|---|---|---|
| **7C + 0L** (parede total) | 6x | `Distance: 20.3 - UsResult 0` — **falso positivo aceito** |
| **4C + 3L** (empate) | 3x | `Distance: 0.0 - UsResult 4` (HIGH_VARIANCE) |
| **5C + 2L / 6C + 1L** | 2x | `Distance: 20.3 - UsResult 1` (WEAK, mas valor errado!) |
| **0C + 7L** (água total) | 9x | `Distance: ~52 - UsResult 0` — correto |
| **Misto L domina** | 7x | `Distance: ~52 - UsResult 1` (WEAK_SIGNAL) |

**Utilidade Diagnóstica do `WEAK_SIGNAL`:** Toda leitura com competição entre parede e água resultou em `WEAK_SIGNAL` ou `HIGH_VARIANCE`. Alta taxa de `WEAK_SIGNAL` = indício de eco parasita competindo com o eco principal.

**Conclusão:** O `min_distance_cm = 25.0 cm` foi fundamental para eliminar falsos positivos silenciosos. A correção necessária agora é garantir que o driver não destrua o ciclo ao detectar um OOR.

---

## Caminhos para Resolver

### 🛠️ Correção 1 — Software Driver (`us_driver.cpp`) — **PRIORIDADE ZERO**

Corrigir `UsDriver::ping_once()` para **SEMPRE executar `timer_hal_->delay_ms(cfg.ping_interval_ms)`**, mesmo em retornos de `OUT_OF_RANGE` ou `TIMEOUT`.

```cpp
// us_driver.cpp — Refatoração com RAII ou delay garantido
Reading UsDriver::ping_once(const UsConfig &cfg)
{
    // Usar ScopeGuard ou garantir delay antes de retornar
    struct ScopeGuard {
        std::shared_ptr<ITimerHAL> timer;
        uint16_t delay_ms;
        ~ScopeGuard() { if (delay_ms > 0 && timer) timer->delay_ms(delay_ms); }
    } guard{timer_hal_, cfg.ping_interval_ms};

    ...
}
```

> **Resultado Esperado:** Se o Ping 1 bater na parede (20.2 cm → `OOR`), o driver aguardará os 70 ms normais. O Ping 2 será disparado em canal limpo e medirá a água em ~69 cm (`OK`), permitindo que o `DOMINANT_CLUSTER` recupere a leitura com sucesso sem gerar falha no App!

---

### 🔩 Correção 2 — Mecânica (Baixar o Sensor na Caixinha)

**Baixar o sensor dentro da caixinha**, afastando-o das paredes laterais e aproximando-o mais do espelho reflexivo.

- Como o cone de som é de ~15°, afastar o sensor do topo da caixa evita que as bordas do pulso atinjam a estrutura de nylon/madeira antes de alcançar o espelho.
- No laboratório, o suporte reflexivo mediu 110 cm sem interferência de parede.

> **Ação:** Baixar o sensor na caixinha e realizar novo teste de campo com a caixa d'água consumida (~69 cm ou mais).

---

### ⚙️ Correção 3 — Reduzir `timeout_us` ao Range Real do Sistema

O `timeout_us = 25000 µs` equivale a um alcance de 428 cm. O range máximo real da caixa d'água é:

$$\text{Distância Máxima Real} = \text{TANK\_HEIGHT} (150) + \text{SENSOR\_OFFSET} (29.5) + \text{Margem} (10.5) = 190\text{ cm}$$

$$\text{Timeout Necessário} = \frac{190 \times 2}{0.0343} \approx 11.080\text{ µs}$$

Reduzir `timeout_us` para **~12.000–13.000 µs** em `us_config` reduz o tempo gasto aguardando pings perdidos em mais de 50%.

> **Nota:** O pulso `ping_duration_us = 20 µs` é o mínimo recomendado para sensores ultrassônicos blindados (à prova d'água) e **NÃO deve ser alterado para 10 µs**.

---

### ⚙️ Correção 4 — Ajuste de `ping_interval_ms` e `PING_COUNT`

- `ping_interval_ms`: Aumentar de 70 ms para **100–120 ms** oferece margem extra de atenuação acústica em caixas profundas e secas.
- `PING_COUNT`: Aumentar de 7 para **9–11 pings** garante que mesmo com 1 ou 2 pings de parede (`OOR`), haverá amostras suficientes de água para o `DOMINANT_CLUSTER` aprovar o ciclo como `OK` com confiança total.

---

## Plano de Ação

- [x] **[Software]** Corrigir `us_driver.cpp` para aplicar `delay_ms(ping_interval_ms)` em todas as ramificações de saída de `ping_once()`.  
  > **Status:** Concluído na v1.1.0 do submódulo `ultrasonic_sensor`. Os delays de inter-ping e warmup foram movidos para o orquestrador `UsSensor`, garantindo o intervalo necessário após qualquer resultado de ping.
- [x] **[Mecânica]** Baixar o sensor dentro da caixinha para reduzir reflexões no cone de 15°.  
  > **Status:** Concluído. O sensor físico foi abaixado em 3.7 cm, resultando em um novo offset de `25.8 cm` (anteriormente `29.5 cm`).
- [x] **[Config]** Atualizar `timeout_us = 13000` em `main.cpp`.  
  > **Status:** Concluído na v0.2.2. O `timeout_us` foi configurado para 13.000 µs (Correção 3). Adicionalmente, o `ping_interval_ms` foi aumentado para 100 ms e o `PING_COUNT` para 9 (Correção 4).
- [ ] **[Validação]** Rodar teste de campo com caixa d'água baixa (>70 cm) e validar ausência de cascatas de TIMEOUT e ausência de falsos `OUT_OF_RANGE`.

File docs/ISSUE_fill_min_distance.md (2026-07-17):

# Issue: `min_distance_cm` desalinhado com a instalação real causou leituras falso-positivas

**Status:** Causa raiz identificada — aguardando calibração final da altura de montagem
**Componente:** `ultrasonic_sensor` (config `UsConfig::min_distance_cm`) + instalação mecânica
**Contexto:** Levantada durante teste de campo (2026-07-15), leituras intermitentes de ~20cm
mesmo com a caixa bem mais cheia que isso.

---

## Causa raiz

`UsConfig::min_distance_cm` estava configurado em **15cm** (valor de teste, antes de
saber a distância mínima real da instalação). Isso fez o próprio componente
`ultrasonic_sensor` **aceitar como válida** qualquer leitura de ~20cm — que na
prática era o sensor captando um refletor rígido próximo (a caixa de madeira/nylon
onde ele estava montado), não a superfície da água.

```cpp
struct UsConfig
{
    uint16_t ping_interval_ms = 70;
    uint16_t ping_duration_us = 20;
    uint32_t timeout_us = 30000;
    Filter filter = Filter::MEDIAN;
    float min_distance_cm = 10.0f;  // <-- estava 15cm nos testes, causa do problema
    float max_distance_cm = 200.0f;
    float max_dev_cm = 15.0f;
    uint16_t warmup_time_ms = 600;
};
```

O componente já possui a lógica correta (`UsResult::OUT_OF_RANGE` quando fora de
`[min_distance_cm, max_distance_cm]`, reportado ao hub) — o problema não era falta
de tratamento, era o **parâmetro de configuração** não refletir a instalação real.

## Evidência de campo

Logs mostrando o comportamento antes da correção mecânica, com `min_distance_cm = 15cm`:

```
UsSensor: 20.2-0, 20.3-0, 20.3-0, 20.3-0, 20.3-0, 20.3-0, 20.3-0
WaterTankApp: Distance: 20.3 - UsResult 0 | Battery: 3810   <- OK, mas é obstrução
```

Ponto importante observado: quando **todos os 7 pings concordam no valor da
obstrução** (refletor fixo dominando o eco), o filtro por variância reporta
`UsResult::OK` com confiança máxima — porque variância baixa não implica leitura
correta, só implica que os pings concordam entre si. Casos de obstrução parcial
(1-2 de 7 pings em ~20cm) já eram corretamente sinalizados como `WEAK_SIGNAL` ou
`HIGH_VARIANCE`; o caso perigoso era só a obstrução total e consistente.

Com `min_distance_cm` ajustado corretamente para a instalação final, esse cenário
passa a ser pego nativamente como `OUT_OF_RANGE` pelo próprio componente, sem
precisar de lógica extra na aplicação.

## Correção mecânica já aplicada

- Sensor estava semi-embutido numa peça de nylon torneada (1cm embutido, cone de
  45°) dentro de um recorte na tampa — possível causa do refletor próximo.
- **Novo arranjo**: sensor agora fica na ponta de um tubo de alumínio de 25mm,
  preso por uma bucha de nylon na tampa — sem nada próximo ao sensor, e com
  **altura ajustável** (dá pra baixar mais sem precisar subir na caixa de novo).
- Distância mínima esperada da instalação atual: **~26-28cm** (nível mais cheio).

## Ação pendente

- [ ] Com a instalação mecânica nova, medir a distância mínima real (nível mais
      cheio) de forma confiável antes de fechar o valor final.
- [ ] Ajustar `min_distance_cm` para um pouco abaixo da distância mínima real
      esperada (margem de segurança, ex: 3-5cm abaixo do mínimo físico), garantindo
      que qualquer leitura de obstrução (~20-22cm, valor já conhecido desse setup)
      caia fora do range e vire `OUT_OF_RANGE` nativamente.
- [ ] Confirmar que o hub recebe e trata corretamente o `OUT_OF_RANGE` reportado
      (esperado, já que o componente já envia isso — só validar em campo com o
      valor de config corrigido).
- [ ] Repetir teste de campo focado, monitorando se leituras espúrias em ~20cm
      desaparecem após a correção mecânica + config.

## Relação com outras issues

Complementa `ISSUE_fill_state_detection.md` — aquela trata de robustez do delta
entre leituras válidas; esta trata de garantir que a leitura em si seja plausível
antes de chegar à lógica de `fill_state`. Com `min_distance_cm` corrigido, a
maior parte do risco identificado ali (leitura obstruída sendo tratada como
válida) já fica coberta no nível do componente, sem precisar de checagem
duplicada na aplicação.

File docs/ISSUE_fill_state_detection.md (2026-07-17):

# Issue: Revisão da lógica de detecção de `FillState`

**Status:** Aberta — aguardando mais dados de campo e geometria validada
**Componente:** `WaterTankLogic::update_fill_state()`
**Contexto:** Levantada durante análise dos primeiros logs de campo (2026-07-14/15)

---

## Motivação

A lógica atual de `update_fill_state()` foi escrita quando o tanque ainda usava
geometria cilíndrica padrão (antes do `tank_geometry.hpp` com os 5 gomos reais).
Com dados de campo em mãos, apareceram dúvidas sobre robustez ao ruído e sobre
o significado físico do threshold em `permille`, que precisam ser resolvidas
antes de fechar o intervalo de wake definitivo (candidato: 60s).

## Código atual

```cpp
struct WaterTankStats
{
    uint16_t level_permille = 0;
    uint16_t last_level_permille = 0;
    FillState fill_state = FillState::UNKNOWN;
    float last_distance_cm = 0.0f;
    ultrasonic::UsResult last_result = ultrasonic::UsResult::HW_FAULT;
    // ... outras coisas (falhas, etc.)
};

void WaterTankLogic::update_fill_state(uint16_t current_permille, WaterTankStats& stats) const
{
    int32_t delta = static_cast<int32_t>(current_permille) - static_cast<int32_t>(stats.last_level_permille);
    uint32_t abs_delta = (delta < 0) ? -delta : delta;
    if (abs_delta < LEVEL_DELTA_MIN) {          // LEVEL_DELTA_MIN = 5
        stats.fill_state = FillState::STABLE;
    }
    else if (delta > 0) {
        stats.fill_state = FillState::FILLING;
    }
    else {
        stats.fill_state = FillState::DRAINING;
    }
}
```

Características da implementação atual:
- Compara **apenas a leitura atual contra a imediatamente anterior** (delta de 1 amostra).
- Threshold fixo em `permille` (`LEVEL_DELTA_MIN = 5`), sem relação explícita com cm.
- Sem janela/histerese — uma única leitura ruidosa pode trocar o estado.

## Dados de campo coletados (2026-07-14)

Dois logs via UDP (`UsSensor` = pings brutos pré-filtro, `WaterTankApp` = distância filtrada):

| Cenário | Range médio (max-min) | Range máx observado | StDev médio |
|---|---|---|---|
| **Estável** (topo, sem vazar, >5min parado) | 0.61 cm | 2.00 cm | 0.24 cm |
| **Enchendo** (primeiros 90s, pedestal balançando) | 1.09 cm | 4.20 cm | 0.37 cm |
| **Enchendo** (5-6 min depois, estabilizado) | 1.09 cm | 2.10 cm | 0.37 cm |
| **Enchendo** (perto do final) | 1.01 cm | 7.40 cm (outlier isolado) | 0.38 cm |

Taxa de enchimento observada (último gomo, bomba ~1400 L/h nominal):
- ~16.5 cm em 927s → **~1.06 cm/min** (~1 cm a cada 60s)

Nenhum erro de `UsResult` (TIMEOUT, HW_FAULT, etc.) apareceu em nenhum dos dois logs —
sensor/filtro se comportaram bem, incluindo durante turbulência.

## Achados

| # | Achado | Severidade | Status |
|---|---|---|---|
| 1 | Delta de 1 amostra é sensível a outliers isolados (ex: pico de 7.4cm observado perto do final do enchimento) — pode disparar transição de estado falsa mesmo pós-filtro | **Alta** | Aberto |
| 2 | `LEVEL_DELTA_MIN = 5` (permille) não tem correspondência documentada em cm — margem real de ruído depende da conversão, que depende da geometria | **Alta** | Aberto |
| 3 | Conversão `permille → cm` não é constante entre gomos (diâmetros diferentes → mesmo delta em permille representa cm diferentes dependendo do segmento) | **Média** | Aberto — depende de `tank_geometry.hpp` estar validado |
| 4 | Com wake de 60s, delta esperado (~1cm) e ruído por amostra (stdev ~0.37cm, outliers até ~7cm) ficam com margem apertada (~3x em condição média, mas outlier isolado pode dominar leitura única) | **Média** | Aberto — ver recomendação abaixo |
| 5 | Sem histerese/confirmação — não há distinção entre "mudou uma vez" e "mudança consistente" | **Média** | Aberto |

## Recomendações a avaliar

1. **Trocar delta de 1 amostra por janela/confirmação.** Exigir N leituras
   consecutivas na mesma direção antes de declarar `FILLING`/`DRAINING` (ex: 2-3
   leituras seguidas com delta > threshold), evitando que um outlier isolado
   dispare a transição.
2. **Documentar/validar a relação `LEVEL_DELTA_MIN` (permille) ↔ cm** por segmento,
   uma vez que `tank_geometry.hpp` esteja calibrado. Se a margem de segurança
   (delta mínimo vs. ruído esperado) variar muito entre gomos, considerar um
   threshold que leve em conta a taxa cm/permille local, não um valor fixo global.
3. **Revisar o intervalo de wake de 60s** à luz do outlier observado (7.4cm) —
   avaliar se a janela de confirmação (item 1) já resolve, ou se vale aumentar
   para 90-120s para folga extra.
4. **Considerar comparar contra média de últimas N leituras** (não só a leitura
   anterior) para suavizar ruído sem precisar esperar confirmação sequencial.
5. **Repetir a análise de ruído/outlier com mais dados de campo** — a amostra
   atual é de um único ciclo de enchimento parcial (último gomo apenas); vale
   confirmar se o padrão se mantém em ciclo completo e em drenagem.

## Próximos passos

- [ ] Validar/fechar `tank_geometry.hpp` (breakpoints e diâmetros dos 5 gomos)
- [ ] Definir método de conversão cm ↔ permille por segmento
- [ ] Prototipar lógica de janela/confirmação e testar contra os logs já coletados
- [ ] Repetir teste de campo com ciclo completo (não só último gomo) para validar em condições variadas
- [ ] Decidir intervalo de wake final para `FILLING`/`DRAINING`

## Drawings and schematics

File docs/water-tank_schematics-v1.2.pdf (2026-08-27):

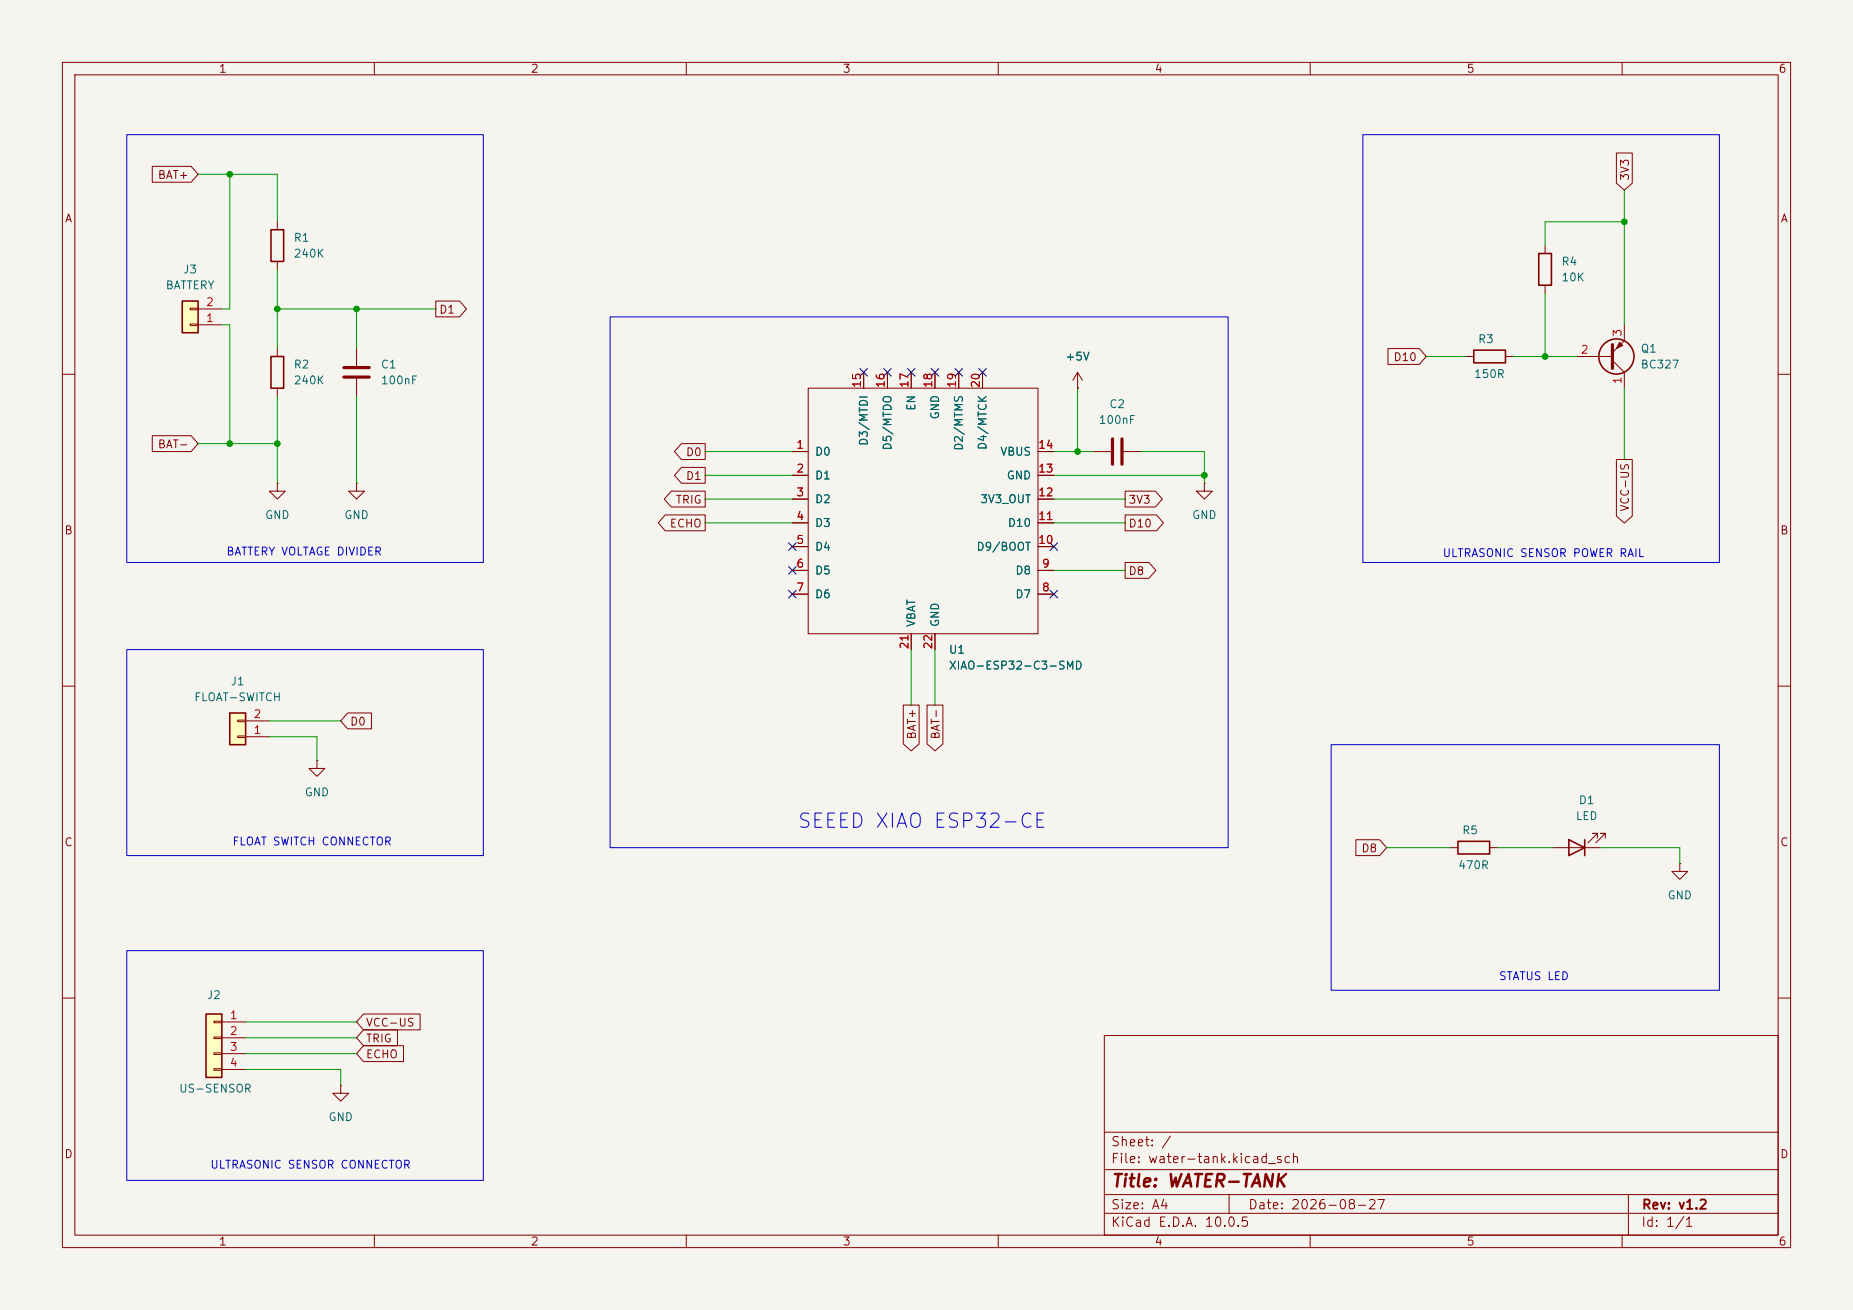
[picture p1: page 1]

Size: A4 | Rev: v1.2
KiCad E.D.A. 10.0.5 | Id: 1/1

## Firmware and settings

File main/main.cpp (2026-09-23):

#include "esp_log.h"
#include "espnow_manager.hpp"
#include "float_switch.hpp"
#include "hal_sleep.hpp"
#include "power_control.hpp"
#include "protocol_types.hpp"
#include "tank_geometry.hpp"
#include "ultrasonic_adapter.hpp"
#include "us_types.hpp"
#include "water_tank_app.hpp"
#include "water_tank_nvs.hpp"
#include "persistence_backend.hpp"
#include "nvs_core.hpp"
#include "secrets.hpp"
#include "ota_manager.hpp"
#include "ota_controller.hpp"
#include "button_ota_trigger.hpp"
#include "tank_command_handler.hpp"
#include "wifi_manager.hpp"

#include "led_controller.hpp"

#include "battery_monitor.hpp"
#include "adc_battery_reader.hpp"
#include "hal_adc_oneshot.hpp"
#include "hal_adc_calibration.hpp"
#include "hal_sys_rom.hpp"
#include "hal_system.hpp"
#include "hal_gpio.hpp"
#include "hal_timer.hpp"
#include "hal_nvs.hpp"
#include "hal_freertos.hpp"
#include "farm_protocol_types.hpp"
#include "time_manager.hpp"
#include "hal_sntp.hpp"
#include "hal_system_time.hpp"
#include <cstdint>

#include "freertos/ringbuf.h"
#include "lwip/sockets.h"

static const char* TAG = "main";

static constexpr bool IS_LOGGING = false;
static constexpr bool ENTER_SLEEP = true;
static constexpr uint16_t LOOP_DELAY_IF_NOT_SLEEPING = 5000;

// Production Configuration for XIAO-ESP32-C3 Mini Board
static constexpr gpio_num_t POWER_GPIO = GPIO_NUM_10;        // D10
static constexpr gpio_num_t US_TRIG_GPIO = GPIO_NUM_4;       // D2
static constexpr gpio_num_t US_ECHO_GPIO = GPIO_NUM_5;       // D3
static constexpr gpio_num_t FLOAT_SWITCH_GPIO = GPIO_NUM_2;  // D0 need be D0-D3 GPIO 3-5 to enable deep-sleep wake-up
static constexpr gpio_num_t BATTERY_LEVEL_GPIO = GPIO_NUM_3; // D1
static constexpr gpio_num_t STATUS_LED_GPIO = GPIO_NUM_8;    // D8 on Xiao ESP32-C3
static constexpr gpio_num_t BOOT_BUTTON_GPIO = GPIO_NUM_9;   // D9

static constexpr const char* CORE_NVS_KEY = "core";
static constexpr const char* STATS_NVS_KEY = "tank_stats";

// HAL instances for sharing across components
static idf_hals::GpioHAL hal_gpio;
static idf_hals::TimerHAL hal_timer;
static idf_hals::SysRomHAL hal_sys_rom;
static idf_hals::SystemHAL hal_system;
static idf_hals::NvsHAL nvs_hal;
static idf_hals::HalFreertos hal_freertos;
static idf_hals::HalSntp hal_sntp;
static idf_hals::HalSystemTime hal_sys_time;
static time_manager::TimeManager time_mgr{hal_sntp, hal_sys_time};

// PowerControl
static power_control::PowerControl power{hal_gpio, POWER_GPIO, /*inverted_logic=*/true, /*initial_on=*/false};

// FloatSwitch config
floatswitch::Config float_switch_config = {
    .gpio = FLOAT_SWITCH_GPIO,
    .normally_open = true,
    .debounce_time_us = 50000,
    .active_level = floatswitch::ActiveLevel::LOW,
    .wakeup_on = floatswitch::WakeupCondition::WHEN_TANK_IS_EMPTY};

static floatswitch::FloatSwitch float_switch{float_switch_config, hal_gpio, hal_timer, hal_sys_rom};

// BatteryMonitor
static idf_hals::HalAdcOneshot oneshot_hal;
static idf_hals::HalAdcCalibration cali_hal;

static battery_monitor::BatteryAdcConfig adc_config = {
    .gpio_num = static_cast<int>(BATTERY_LEVEL_GPIO),
    .sample_count = 16,
    .sample_delay_us = 1000,
    .enable_calibration = true};

static battery_monitor::BatteryMonitorConfig monitor_config = {
    .divider_top_ohms = 240000,
    .divider_bottom_ohms = 240000,
    .chemistry = battery_monitor::BatteryChemistry::LI_ION_18650};

static battery_monitor::AdcBatteryReader adc_reader{oneshot_hal, cali_hal, hal_sys_rom, adc_config};
static battery_monitor::BatteryMonitor bat_monitor{adc_reader, monitor_config};

// Ultrasonic Sensor
ultrasonic::UsConfig us_config{
    .ping_interval_ms = 100,
    .ping_duration_us = 20,
    .timeout_us = 13000,
    .filter = ultrasonic::Filter::DOMINANT_CLUSTER,
    .min_distance_cm = SENSOR_MIN_DISTANCE_CM,
    .max_distance_cm = SENSOR_MAX_DISTANCE_CM,
    .warmup_time_ms = 0};

static ultrasonic::UsSensor
    sensor_us{hal_gpio, hal_timer, hal_sys_rom, hal_freertos, US_TRIG_GPIO, US_ECHO_GPIO, us_config};
static UltrasonicLevelSensorAdapter sensor_adapter{sensor_us};

// SleepHAL
static idf_hals::SleepHAL sleep_hw;

// Persistence and App instantiation
static RTC_DATA_ATTR CoreStorage g_rtc_core;
static RtcBackend rtc_core_backend(&g_rtc_core, sizeof(CoreStorage));
static NvsBackend nvs_core_backend{nvs_hal, CORE_NVS_KEY};
static NvsCore nvs_core{rtc_core_backend, nvs_core_backend};

static RTC_DATA_ATTR WaterTankStorage g_rtc_tank;
static RtcBackend rtc_stats_backend(&g_rtc_tank, sizeof(WaterTankStorage));
static NvsBackend nvs_stats_backend{nvs_hal, STATS_NVS_KEY};
static WaterTankNvs nvs_tank{rtc_stats_backend, nvs_stats_backend};

// TankGeometry
static TankGeometry geometry{SENSOR_OFFSET_CM};

// WaterTankLogic
static WaterTankLogic logic{geometry, float_switch};

// OtaManager — HAL implementations
static HttpClient http_client;
static ManifestParser manifest_parser;
static OtaSession ota_session;
static System ota_system;
static TaskScheduler task_scheduler;
static RollbackManager rollback_manager;
static OtaDependencies ota_deps = {
    .http_client = http_client,
    .manifest_parser = manifest_parser,
    .ota_session = ota_session,
    .system = ota_system,
    .task_scheduler = task_scheduler,
    .rollback_manager = rollback_manager,
};

static OtaConfig ota_config{
    .device_type = "water_tank",
    .manifest_url = SERVER_URL,
    .task_stack_size = 8192,
    .task_priority = 5,
    .transport = {.manifest_timeout_ms = 30000, .firmware_timeout_ms = 30000},
    .security = {.allow_http_during_development = true},
    .allow_same_version = false,
    .restart_on_success = false,
};
static OtaManager ota_manager(ota_deps);
static OtaController ota_controller(ota_manager, hal_freertos);

// OTA triggers: boot button
static ButtonOtaTrigger btn_trigger(hal_gpio, hal_freertos, BOOT_BUTTON_GPIO, 200);

// Status LED Controller
static LedConfig led_config{
    .gpio_num = STATUS_LED_GPIO,
    .task_stack_size = 2048,
    .task_priority = 1,
    .active_level = 1,
};
static LedController led_controller{hal_gpio, hal_freertos, led_config};

#include "udp_logger.hpp"

extern "C" void app_main()
{
    ESP_LOGW(TAG, "Initializing Smart Farm Water Tank...");
    // hal_freertos.task_delay(pdMS_TO_TICKS(3000));

    // Create ESP-NOW receive queue
    QueueHandle_t app_rx_queue = hal_freertos.queue_create(30, sizeof(espnow::AppMessage));

    // Retrieve singleton references for DI
    auto& wifi = wifi_manager::WiFiManager::get_instance();
    auto& espnow = espnow::EspNowManager::instance();

    // Command Handler
    TankCommandHandler command_handler{app_rx_queue, espnow, time_mgr, hal_timer, hal_freertos};

    // Instantiate app with dependencies
    WaterTankApp app(
        nvs_core,
        nvs_tank,
        sensor_adapter,
        float_switch,
        espnow,
        app_rx_queue,
        command_handler,
        power,
        sleep_hw,
        bat_monitor,
        hal_timer,
        hal_freertos,
        logic,
        wifi,
        ota_controller,
        btn_trigger,
        hal_system,
        time_mgr,
        led_controller);

    // Initialize application state (enable remote logging for field tests)

    if (app.init(IS_LOGGING) != ESP_OK) {
        ESP_LOGE(TAG, "Critical hardware/application initialization failure. Entering safe deep sleep for 1 minute.");
        sleep_hw.enable_timer_wakeup(1ULL * 60ULL * 1000ULL * 1000ULL);
        sleep_hw.deep_sleep_start();
        return;
    }

    // Run the main application flow in a loop if not sleeping
    while (app.run(ENTER_SLEEP)) {
        hal_freertos.task_delay(pdMS_TO_TICKS(LOOP_DELAY_IF_NOT_SLEEPING));
    }
}

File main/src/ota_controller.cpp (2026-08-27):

// main/src/ota_controller.cpp
#include "ota_controller.hpp"

#undef LOG_LOCAL_LEVEL
#define LOG_LOCAL_LEVEL ESP_LOG_INFO
#include "esp_log.h"

static const char* TAG = "OtaController";

static farm::OtaErrorCode map_fail_reason(OtaFailReason reason);

OtaController::OtaController(IOtaManager& ota_manager, idf_hals::IHalFreertos& hal_freertos)
    : ota_manager_(ota_manager)
    , hal_freertos_(hal_freertos)
{
}

bool OtaController::init(const OtaConfig& config)
{
    return ota_manager_.init(config);
}

bool OtaController::check_pending_verify() const
{
    return ota_manager_.check_pending_verify();
}

std::optional<OtaVersion> OtaController::get_running_version() const
{
    return ota_manager_.get_running_version();
}

void OtaController::rollback_and_reboot()
{
    ESP_LOGE(TAG, "Triggering rollback and reboot...");
    ota_manager_.rollback_and_reboot();
}

OtaActionResult OtaController::confirm_firmware(bool session_healthy)
{
    OtaActionResult result = {};

    if (!session_healthy || !ota_manager_.confirm_app_valid()) {
        result.success = false;
        result.exec_result = farm::OtaExecResult::ROLLBACK_TRIGGERED;
        result.error_code =
            !session_healthy ? farm::OtaErrorCode::HEALTH_CHECK_FAILED : farm::OtaErrorCode::PARTITION_CONFIRM_FAILED;

        ESP_LOGE(TAG, "Firmware verification failed (reason: %d)", static_cast<int>(result.error_code));
        return result;
    }

    result.success = true;
    result.exec_result = farm::OtaExecResult::CONFIRMED_SUCCESS;
    result.error_code = farm::OtaErrorCode::NONE;

    return result;
}

OtaActionResult OtaController::execute_download(uint32_t timeout_ms)
{
    OtaActionResult result = {};

    if (!ota_manager_.start_ota()) {
        ESP_LOGE(TAG, "Failed to start OTA download session");
        result.success = false;
        result.exec_result = farm::OtaExecResult::DOWNLOAD_FAILED;
        result.error_code = farm::OtaErrorCode::DOWNLOAD_SESSION_FAIL;
        return result;
    }

    uint32_t elapsed_ms = 0;
    OtaStatus status = ota_manager_.get_status();

    while (status != OtaStatus::READY_TO_RESTART && status != OtaStatus::FAILED && elapsed_ms < timeout_ms) {
        hal_freertos_.task_delay(pdMS_TO_TICKS(500));
        elapsed_ms += 500;
        status = ota_manager_.get_status();
    }

    if (status == OtaStatus::READY_TO_RESTART) {
        ESP_LOGI(TAG, "OTA download completed successfully. Ready to restart.");
        result.success = true;
        result.exec_result = farm::OtaExecResult::CONFIRMED_SUCCESS;
        result.error_code = farm::OtaErrorCode::NONE;
    }
    else {
        result.success = false;
        result.exec_result = farm::OtaExecResult::DOWNLOAD_FAILED;
        if (status == OtaStatus::FAILED) {
            OtaFailReason reason = ota_manager_.get_last_error();
            result.error_code = map_fail_reason(reason);
            ESP_LOGE(
                TAG,
                "OTA download failed (reason: %d, error_code: %d)",
                static_cast<int>(reason),
                static_cast<int>(result.error_code));
        }
        else if (elapsed_ms >= timeout_ms) {
            result.error_code = farm::OtaErrorCode::WATCHDOG_TIMEOUT;
            ESP_LOGE(TAG, "OTA global watchdog timeout (>%u ms)", timeout_ms);
        }
        ota_manager_.cancel_ota();
    }
    return result;
}

static farm::OtaErrorCode map_fail_reason(OtaFailReason reason)
{
    switch (reason) {
    case OtaFailReason::MANIFEST_URL_INVALID:
    case OtaFailReason::MANIFEST_INVALID:
        return farm::OtaErrorCode::MANIFEST_PARSE_ERROR;

    case OtaFailReason::MANIFEST_HTTP_FAIL:
    case OtaFailReason::FIRMWARE_URL_INVALID:
    case OtaFailReason::DOWNLOAD_HTTP_FAIL:
        return farm::OtaErrorCode::HTTP_DOWNLOAD_FAILED;

    case OtaFailReason::DEVICE_TYPE_MISMATCH:
        return farm::OtaErrorCode::DEVICE_TYPE_MISMATCH;

    case OtaFailReason::CURRENT_VERSION_PARSE_FAIL:
    case OtaFailReason::VERSION_NOT_NEWER:
    case OtaFailReason::DOWNLOAD_IMAGE_VERSION_FAIL:
        return farm::OtaErrorCode::VERSION_NOT_NEWER;

    case OtaFailReason::DOWNLOAD_SESSION_FAIL:
    case OtaFailReason::DOWNLOAD_IMAGE_DESC_FAIL:
        return farm::OtaErrorCode::DOWNLOAD_SESSION_FAIL;

    case OtaFailReason::DOWNLOAD_FINISH_FAIL:
    case OtaFailReason::HASH_PARTITION_FAIL:
        return farm::OtaErrorCode::FLASH_WRITE_ERROR;

    case OtaFailReason::HASH_MISMATCH:
        return farm::OtaErrorCode::IMAGE_HASH_MISMATCH;

    case OtaFailReason::NONE:
    default:
        return farm::OtaErrorCode::UNKNOWN_ERROR;
    }
}

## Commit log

2026-07-08 initial commit: app code, config, and host tests layout
    [partitions.csv]
2026-07-08 add submodules wifi_manager, floatswitch, power_control, ultrasonic_sensor, espnow_manager, ota_manager, and smart-farm-common
2026-07-09 feat: integrate OTA manager with hardware button trigger and application-specific controller
2026-07-09 docs: add guide for configuring monitor-only mode to prevent battery drain
2026-07-09 fix: update deep sleep log message unit from microseconds to seconds
    [water_tank_app.cpp]
2026-07-09 chore: track submodules on main
2026-07-09 feat(battery_monitor): initial file structure
2026-07-10 feat(battery_monitor): implement component classes, HALs, and setup host tests
2026-07-10 test(battery_monitor): implement comprehensive unit tests for BatteryMonitor and AdcBatteryReader
2026-07-10 docs(battery_monitor): create API.md documentation
2026-07-10 docs(battery_monitor): create README.md with architectural decisions and examples
2026-07-10 feat(app): integrate battery_monitor component into WaterTankApp orchestration
2026-07-10 docs(battery_monitor): create CHANGELOG.md detailing v1.0.0
2026-07-10 refactor(battery_monitor): remove local battery_monitor component files to prepare for submodule integration
2026-07-10 feat(battery_monitor): integrate battery_monitor as a git submodule on main branch
2026-07-10 refactor(battery_monitor): update battery_monitor submodule pointer with config validation improvements
2026-07-10 refactor(battery_monitor): update battery_monitor submodule pointer with configuration docs
2026-07-10 refactor(battery_monitor): update battery_monitor submodule pointer with doc changes
2026-07-10 fix: update battery_monitor submodule to fix missing unit_id initializer
2026-07-10 Refactor: simplify battery_monitor driver and move battery logic to WaterTankLogic
2026-07-10 Fix base project main.cpp battery config and update submodule references
    [main.cpp]
2026-07-11 docs: fix MONITOR_ONLY_GUIDE.md and apply monitor-only float switch config
    [main.cpp]
2026-07-11 refactor: remove NvsAdapter and TimerAdapter, pass unified HALs directly to components
2026-07-12 refactor(main): replace raw FreeRTOS primitives with IHalFreertos wrapper in WaterTankApp
    [main.cpp, test_water_tank_app.cpp, water_tank_app.cpp]
2026-07-12 fix: change buttonOtaTrigger hold_ms time to 200ms, since total run of app from start to deep sleep is no longer than 1500ms
    [main.cpp]
2026-07-13 feat: loop water tank app run flow continuously every 5000ms instead of entering deep sleep
2026-07-13 fix: connect to WiFi synchronously during setup before initializing ESP-NOW
    [main.cpp]
2026-07-13 fix: change wifi connect order to after espnow init, to avoid channel conflicts
    [main.cpp]
2026-07-15 fix: remove unused componentes in filed test
    [main.cpp, water_tank_app.cpp]
2026-07-17 fix: correct tank geometry with field data
    [tank_geometry.ods]
2026-07-17 doc: tank geometry sheet and issues
    [tank_geometry.ods]
2026-07-17 fix: correct sensor distance and permile log
    [water_tank_app.cpp, water_tank_types.hpp]
2026-07-19 fix: coorect offset sensor new hardware reflexive v0.2.1
    [main.cpp, water_tank_app.cpp, water_tank_types.hpp]
2026-07-20 refactor(i_level_sensor): add sample_count parameter to read_level()
    - Add sample_count parameter to ILevelSensor::read_level(uint8_t sample_count)
    - Remove hardcoded ping_count_ from UltrasonicLevelSensorAdapter and forward sample_count
    - Add static LEVEL_SAMPLE_COUNT constant to WaterTankApp
    - Update MockLevelSensor and host test assertions accordingly
2026-07-20 feat: inject system hal and implement reboot command handling
    [main.cpp, test_water_tank_app.cpp, water_tank_app.cpp]
2026-07-20 doc: issue out of range - reflexive sensor
2026-07-20 doc: issue out of range - bug in us sensor (ultrasonic_sensor)
2026-07-20 refactor: integrate cross-platform HAL improvements for ESP32 target compatibility
2026-07-20 doc: tank geometry
    [tank_geometry.ods]
2026-07-20 fix: apply physical offset correction and timing optimization for reflexive sensor
    - Lowered physical offset from 29.5cm to 25.8cm (reduction of 3.7cm)
    - Reduced timeout_us from 25000 to 13000 for faster recovery
    - Increased ping_interval_ms from 70 to 100
    - Increased PING_COUNT from 7 to 9
    - Updated TankGeometry constructor and member to float
    - Re-added temporary individual ping logs
    - Bumped version to 0.2.2 for OTA
    [main.cpp, water_tank_types.hpp]
2026-07-21 feat(espnow): enable EspNowManager and set ChannelPolicy::FIXED post WiFi connect
    [main.cpp]
2026-07-21 chore: update ultrasonic_sensor submodule pointer
2026-07-23 doc: field behavior profile of RCWL-1655 sensor
2026-07-23 fix: use farm codespace (smart-farm-common farm_protocol_types.hpp) in source code
    [water_tank_stats.hpp]
2026-07-23 doc: tank geometry patterns
    [tank_geometry.ods]
2026-07-23 fix: correct wifi connection sync mode to wait for ip before going to water_tank_app run
    [main.cpp]
2026-07-23 refactor: integrate REBOOT and SLEEP_OVERRIDE logic from main branch to prevent merge conflicts
    [main.cpp, test_water_tank_app.cpp, water_tank_app.cpp]
2026-07-23 fix: disconnect wifi before reboot
    [water_tank_app.cpp]
2026-07-23 refactor: disconnect WiFi safely before system restart in both OTA success and REBOOT command paths
    [water_tank_app.cpp]
2026-07-24 docs: field tests ultrasonic logs
2026-07-27 fix: - WaterTankNvs (like NvsCore) uses RTC and NVS backends - WaterTankNvs no longer inherits from NvsCore, it's an autonomous class with its own interface - WaterTankStorageAdapter deleted, no long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
    [main.cpp, water_tank_app.cpp, water_tank_stats.hpp]
2026-07-27 fix: init storage init_core_storage and init_tank_storage handle ESP_ERR_NVS_NOT_FOUND, make first data and force commit to NVS
    [main.cpp, water_tank_app.cpp]
2026-07-27 fix: revert app to deep sleep
    [water_tank_app.cpp, water_tank_types.hpp]
2026-07-27 refactor: WaterTankNvs and tests
    - water_tank_app.cpp: remove sensor warmup from run, remove delay from while loop on run
    - water_tank_nvs.cpp: implements calculate_crc template, now WaterTankNvs is no longer : public NvsCore
    - test_water_tank_nvs.cpp: host tests to water_tank_nvs
    [water_tank_app.cpp]
2026-07-28 feat: add read_level(sample_count) to change sampling count on the fly
2026-07-28 refactor(app run): improves error handling on WaterTankApp::run()
    [water_tank_app.cpp]
2026-07-29 fix: add init to i_level_sensor and ultrasonic_adapter, so it can init the sensor
2026-07-29 refactor(app): update WaterTankApp lifecycle, init error handling and run flow
    - Add enter_sleep parameter to run() for easier testing without deep sleep
    - Optimize sensor warmup by overlapping battery and float switch reads
    - Add session health tracking and firmware verification before sleep
    - Handle ESP-NOW recovery scan wait and report retries
    - Reset core and tank storage commit flags upon successful saves
    [main.cpp, water_tank_app.cpp, water_tank_types.hpp]
2026-07-29 fix(process_pending_ota): app send esp-now message if error and not connected_by_us
    [water_tank_app.cpp]
2026-07-29 refactor(app): simplify process_pending_ota and add failure reporting helper
    [water_tank_app.cpp]
2026-07-29 fix: unfiltered logs on gitignore
    [water_tank_app.cpp]
2026-07-29 docs & fix: document main task stack size requirement and log high water mark
    [water_tank_app.cpp]
2026-07-30 refactor: integrate unified smart-farm-common and resolve dependencies
    [main.cpp, water_tank_app.cpp]
2026-07-30 test: add direct unit tests for WaterTankApp methods and fix mock timer loop
    [main.cpp, test_water_tank_app.cpp, water_tank_app.cpp]
2026-07-31 fix(stats): unify VERSION type and add version validation in WaterTankNvs
    [main.cpp, water_tank_app.cpp, water_tank_stats.hpp]
2026-08-01 fix(water-tank): fix 64-bit timestamp format specifier in ESP-NOW sync log
    [water_tank_app.cpp]
2026-08-02 chore: update submodules with new idf_hals with i2c_hal
2026-08-03 fix: wifi connection if logging and version
    [water_tank_app.cpp]
2026-08-03 fix(water-tank): remove fill_state packing in report.status
    [water_tank_app.cpp]
2026-08-04 fix: new SENSOR_OFFSET_CM = 25.6 after phisical sensor changes
    [water_tank_types.hpp]
2026-08-04 fix: minimum distance sensor = 21
    [water_tank_types.hpp]
2026-08-05 refactor(water_tank_app): process all queued commands and move report retry before listen window
    - Prevent dropping queued commands (e.g. SYNC_TIME) by not breaking early on SLEEP_OVERRIDE in listen_for_messages()
    - Change process_command return type to void
    - Extract create_report() helper and pass WaterLevelReport to send_report()
    - Perform report retry immediately after initial transmit check
    - Update host unit tests and MockWiFiManager interface alignment
    [test_water_tank_app.cpp, water_tank_app.cpp]
2026-08-05 test(water_tank_app): add coverage tests for time sync request, multiple commands, pairing, and sensor retry
2026-08-06 bump: version 0.3.0
    - Add multi-sample FillState transition confirmation window to filter single-sample noise.
    - Implement graceful peripheral deactivation (espnow_.deinit()) before deep sleep and system restarts.
    - Add command ACK handling and 100ms task delay before rebooting on REBOOT command.
    - Refactor process_command into clean switch statements.
    - Modularize WaterTankApp::run logging into step-by-step logs and remove duplicate error prints.
    [test_water_tank_app.cpp, water_tank_app.cpp, water_tank_stats.hpp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]
2026-08-06 submodule: update ultrasonic_sensor component to v1.1.1
2026-08-07 feat(water-tank): include PowerProfile in reports and remove active request_time_sync
2026-08-21 fix(espnow): configure logical ack retries for recovery scan and update espnow_manager submodule
    [water_tank_app.cpp]
2026-08-21 chore: update ultrasonic submodule
2026-08-21 refactor(app): streamline wifi connect/disconnect flow and cleanup host_test mocks
2026-08-21 refactor(ota): streamline OTA verification and failure handling flow
    [test_water_tank_app.cpp, water_tank_app.cpp]
2026-08-21 refactor(battery): delegate percentage and state classification to battery_monitor component
2026-08-21 chore(submodules): update battery_monitor and power_control submodule pointers
2026-08-21 feat(led): inject LedController into WaterTankApp and configure status LED on GPIO 8
2026-08-21 feat(led): integrate status LED patterns across WaterTankApp lifecycle and add host tests
2026-08-22 fix(led): ensure pulse(30) is used on report transmission and update tests
    [test_water_tank_app.cpp, water_tank_app.cpp]
2026-08-22 feat(led): use set_pattern(BlinkPattern::TX_PULSE) on report send and update unit test expectations
2026-08-22 docs: add schematics
2026-08-27 feat(ota): extract IOtaController interface and OtaController component
    - Create IOtaController interface and concrete OtaController component
    - Inject IOtaController into WaterTankApp, removing inline polling and error mapping
    - Add MockOtaController and dedicated host test suite in test_ota_controller
    - Add UDP_LOG_SERVER_IP and UDP_LOG_PORT configuration in secrets.example.hpp
    - Update WaterTankAppTest suite for IOtaController
    - Bump version to 0.3.12 and update CHANGELOG.md
    [main.cpp, ota_controller.cpp, test_water_tank_app.cpp]
2026-08-27 feat(logic): add adaptive nighttime sleep schedule (15 min between 22h-06h)
    - Add TIMER_STABLE_NIGHT_US (15 min) between NIGHT_START_HOUR (22h) and NIGHT_END_HOUR (06h)
    - Pass is_night bool to WaterTankLogic::calculate_sleep_time_us
    - Keep 5 min interval during daytime and active evening (06h-22h)
    - Keep immediate 2 min drain and 1 min fill priorities at all times
    - Add unit test coverage in WaterTankLogicTest
    - Bump version to 0.4.1
2026-08-27 docs: kicad schematics files
    [water-tank.kicad_sch]
2026-08-29 fix: process_pending_ota save storage before reboot on successful OTA, rearm btn_trigger after failed OTA.
    [water_tank_app.cpp]
2026-09-15 fix: improve channel recovery flow, sync wifi start, and update espnow_manager (v0.4.4)
    [test_water_tank_app.cpp, water_tank_app.cpp]
2026-09-23 feat: enable float switch wakeup on empty tank (v0.4.5)

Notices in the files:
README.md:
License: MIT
